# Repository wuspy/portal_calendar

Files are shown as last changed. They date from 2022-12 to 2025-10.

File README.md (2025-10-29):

# Portal Calendar

An ESP32 based, Portal themed e-ink calendar that can run on AAA batteries for years, with optional weather integration through OpenWeatherMap.

- [Bill of Materials](#bill-of-materials)
- [Assembly](#assembly)
- [Firmware](#firmware)
  - [Building with Arduino IDE](#building-with-arduino-ide)
  - [Building with PlatformIO](#building-with-platformio)
- [More Info](#more-info)
  - [Timekeeping](#timekeeping)
  - [Graphics](#graphics)
- [Changelog](#changelog)
- [License](#license)

This project was inspired by Reddit user u/feefifofeddit who made [a prototype of a Raspberry Pi-powered Portal calendar](https://www.reddit.com/r/RASPBERRY_PI_PROJECTS/comments/qujt3i/wip_portal_desktop_calendar/). Unfortunately the display they used has been discontinued, and I wanted a battery powered and wall mountable version, so I designed my own based on the ESP32 platform with the goal of being as low-power and game accurate as possible.

By default, chamber hazard icons from both Portal and Portal 2 are shown below the current date. Portal icons are shown for day 1 through 16, while Portal 2 icons are shown for day 17 through 31.

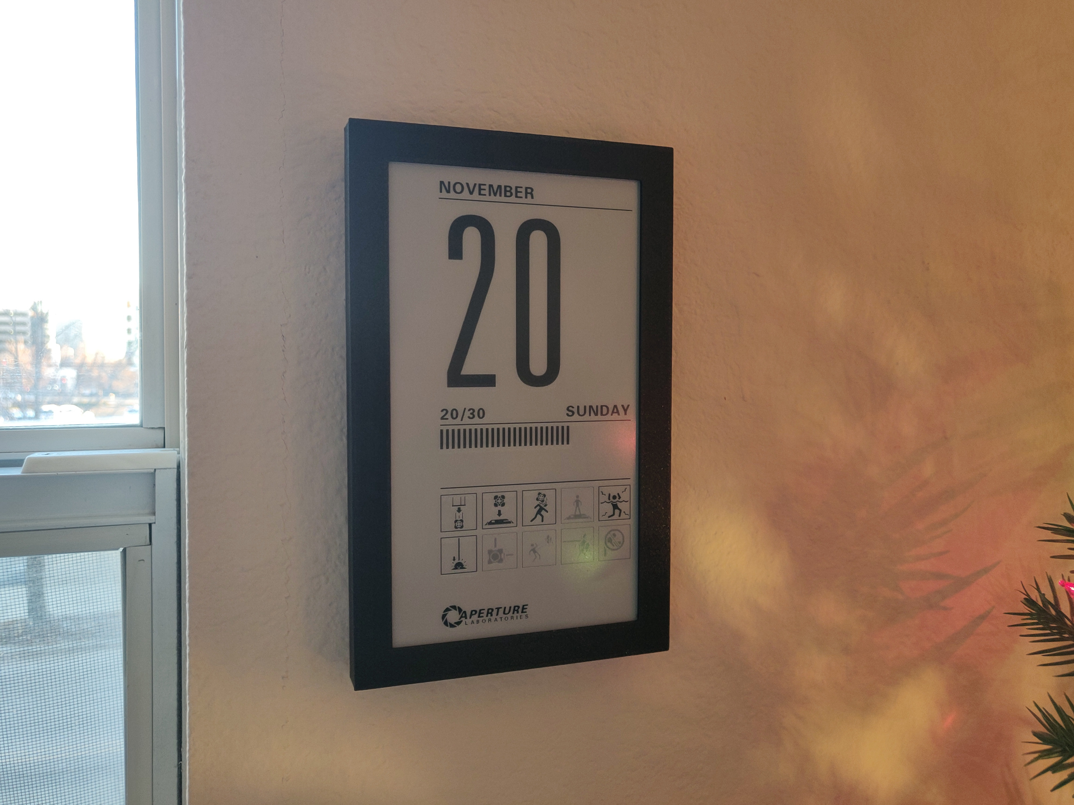
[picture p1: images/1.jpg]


With the weather feature enabled, the chamber hazard icons are replace by either a 5-day or 12-hour weather forecast provided by OpenWeatherMap that shows the average weather condition, the high & low temperatures, the chance of rain, or the humidity, at your preference.

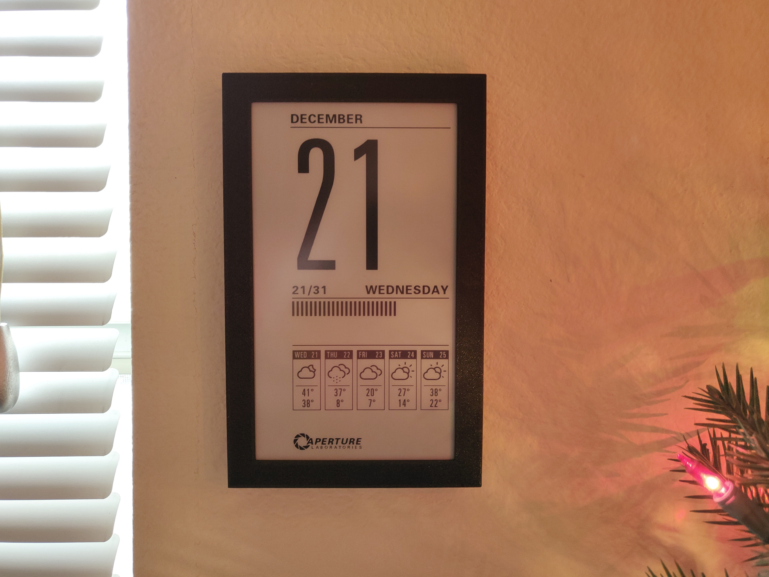
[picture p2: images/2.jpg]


The weather icons are based on the designs by Lukas Bischoff and Erik Flowers, available [here](https://github.com/erikflowers/weather-icons/).

# Bill of Materials

- **Waveshare 7.5" 800x480 E-Ink display**

    Available [directly from Waveshare](https://www.waveshare.com/product/displays/e-paper/epaper-1/7.5inch-e-paper-hat.htm) or [from Amazon](https://www.amazon.com/gp/product/B075R4QY3L). The display itself is the Good Display GDEW075T7, Waveshare just resells it and gives you a breakout board.

    Make sure you buy the bare display with breakout board. Don't buy the one preinstalled in a case. Don't buy the Black/White/Red version of this display either, just the standard Black/White one.

    This display is intended only for 2-color greyscale (full black or full white, with no grey levels). However, this code does some hacks to it to make it support 4-color greyscale for better antialiasing. I didn't invent this technique, the [GxEPD2](https://github.com/ZinggJM/GxEPD2_4G) project among others does the same thing. The downside of doing this, however, is that results can vary from display to display. The greyscale levels may not look as good on your particular display as they do on mine. I've tried to design the graphics with that in mind so that the grey level isn't critical to get things to look good, but I've only tried this on two of these displays, and I can't guarantee yours will look perfect.

- **EzSBC ESP32 breakout board**

    Available [here](https://www.ezsbc.com/product/esp32-breakout-and-development-board/) or [here](https://www.tindie.com/products/ddebeer/esp32-dev-board-wifibluetooth/). This will run on any ESP32, but this particular board is perfect for alkaline battery power due to its efficient voltage regulator and flexible input voltage. If you use a different board, you will need to modify the case and come up with your own power solution.

- **4xAAA battery holder**

    Pretty much all of them will work. [This is a good one](https://www.pololu.com/product/1145/specs).

- **9x M3x8 cap head screws**

# Assembly

Before you begin, note that this project does require soldering and cutting the included display wiring harness. Since it's the most expensive part of the project, I recommend testing your display first before cutting anything so you can easily return it if it's defective. The breakout board comes with pin headers you can solder and directly connect to the stock wiring harness, so I highly recommend skipping down to step 5 and connecting everything up to make sure the dispaly works first. Once you've done that, desolder the pin headers from the breakout board and follow these instructions from the beginning.

1. Print [front.stl](frame/front.stl) and [back.stl](frame/back.stl). Once those are done you can start putting things together, and get [cover.stl](frame/cover.stl) printing while you work. Print with a **0.2mm layer height**, other than that print settings really don't matter that much.
2. Remove the protective film on the front of the e-ink display if it has one (there should be a colored tab in one corner you can pull).
3. Insert the display into [front.stl](frame/front.stl), oriented so the ribbon cable goes into slot on the side. The easiest way to do this is to gently pre-bend the ribbon cable, then slide the display in from the opposite side.

    

    This should go without saying, but the display and the ribbon cable connection are very fragile. Here's a close-up of how the ribbon cable should seat in the slot.

    Recent versions of this display have a slimmer ribbon cable than shown in these pictures, however it should be the same length and have the same pinout, and is fully compatible.

    

    Once it's inserted, make sure the display is sitting flat and that the edges of the display are flush with the edges of the case on the top and bottom.

4. Insert [back.stl](frame/back.stl) on top of the display, flat side down, being careful that the ribbon cable doesn't get snagged when sliding in the slot on the side.

   

   The back cover should be flush with the edges of the front cover. If it's not, the display may not be seated correctly in the front cover. Don't try to force it, remove the back cover and re-seat the display.

   Once the back cover is installed, you can secure it with an **M3x8** screw in each corner.

5. Insert the e-Paper Driver HAT into the slot by the ribbon cable and clip the ribbon cable into the connector. Make sure you get it fully seated in the connector, and **make sure to latch it closed**, otherwise the display may not work when you try to power it on. Also, make sure the **Display Config** switch is in the **B** position, and the **Interface Config** switch is in the **0** position.

6. Now the fun part begins, cutting wires to length and soldering them to the ESP32. Note the colors listed below are the ones used in the wiring harness I got, yours is probably the same but it may be different if Waveshare changed it.

    Note that the PWR pin does not exist prior to revision 2.3 of the waveshare driver board. If you have revision 2.2 or earlier, ignore that pin in the chart below. The firmware will work with both, no other changes are needed.

    | e-Paper HAT   |     | ESP32 |
    | ------------  | --- | ----- |
    | VCC (Grey)    | <-> | 3.3v  |
    | GND (Brown)   | <-> | GND   |
    | DIN (Blue)    | <-> | IO13  |
    | CLK (Yellow)  | <-> | IO14  |
    | CS (Orange)   | <-> | IO15  |
    | DC (Green)    | <-> | IO23  |
    | RST (White)   | <-> | IO33  |
    | BUSY (Purple) | <-> | IO27  |
    | PWR (Red)     | <-> | IO32  |

7. Glue in the battery holder (I used JB weld plastic bonder), and solder the red and black wires to the **Vin** and **GND** pins on the ESP32.

    Here's what everything should look like once wired up. Note that this photo shows the older waveshare driver board without PWR pin.

    

8. Make sure all the wires are inside the recess on the back cover so they aren't pinched, and make sure the ESP32 is seated in its recess. Then you can install [cover.stl](frame/cover.stl) and secure it with an **M3x8** screw in each corner, and one in the center above the battery holder.

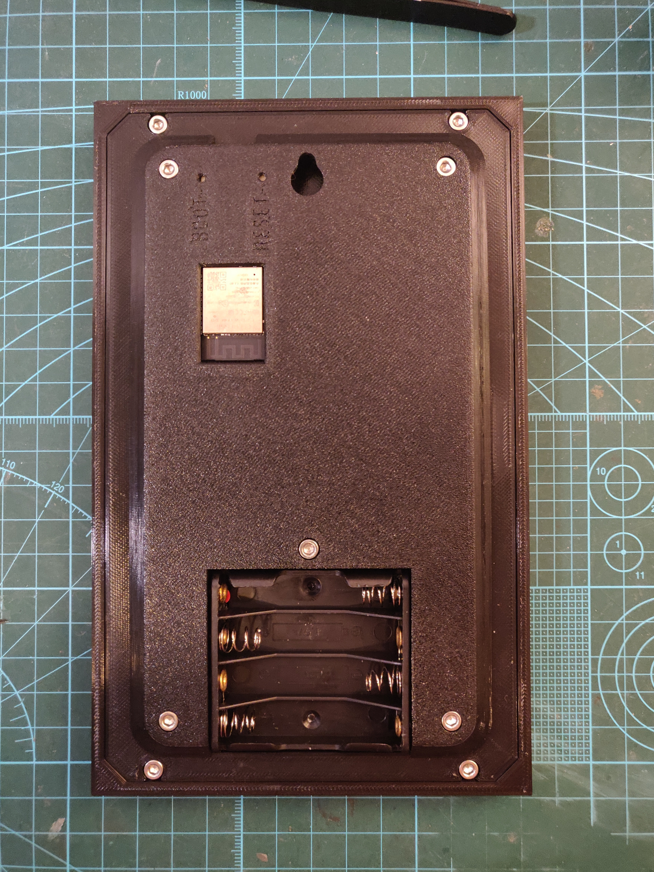
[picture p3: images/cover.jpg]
    

    There's no point in putting the batteries in yet since the ESP32 still needs to be programmed.

# Firmware

## Building with Arduino IDE

This project requires the following dependencies to be installed through the library manager

 - **ArduinoJson** by Benoit Blanchon - 7.4.1
 - **ESP Async WebServer** by ESP32Async - 3.7.7
 - **Async TCP** by ESP32Async - 3.4.1

 Make sure you install the correct versions of these libraries, and for ESP Async WebServer and Async TCP, **install the ones by ESP32Async**, as there are many forks of these libraries out there and I can't guarantee compatability with any others.

 You also need to install the ESP32 board package 3.0+. Go to `Tools -> Board -> Boards Manager...` and search for "esp32". **Install the one by Espressif Systems, not Arduino.**

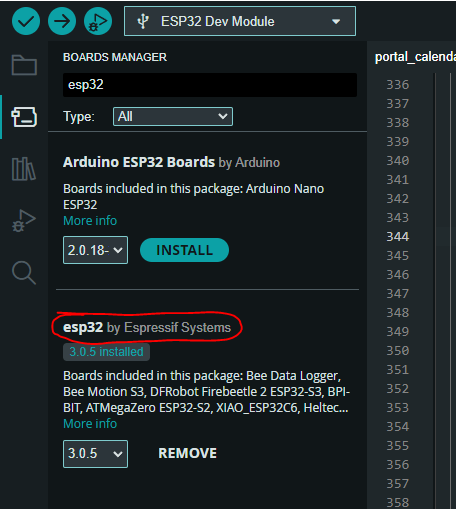
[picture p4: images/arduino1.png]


If you can't find the esp32 board package, you might need an additional board manager URL for it. This shouldn't be necessary anymore, but I'm still including this step just in case. Go to `File -> Preferences` and add the following URL to `Additional Boards Manager URLs`

    https://raw.githubusercontent.com/espressif/arduino-esp32/gh-pages/package_esp32_index.json

After the board package is installed, go to `Select Board -> Select other board and port...` and select `ESP32 Dev Module` for your board.

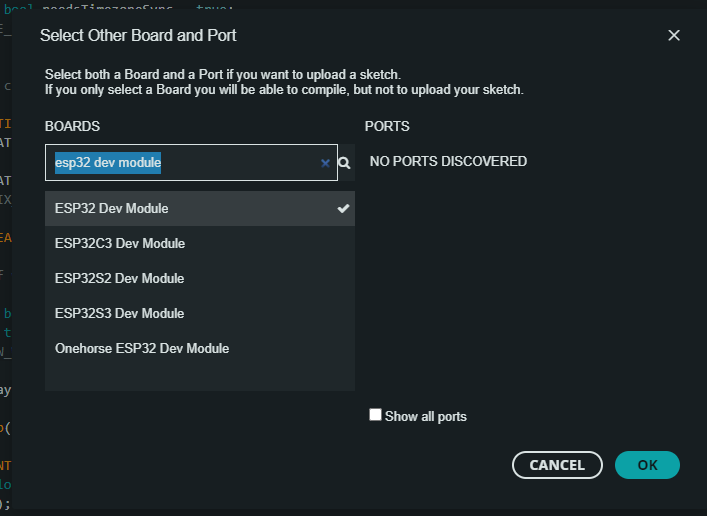
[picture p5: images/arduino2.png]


Once that's selected you'll see a bunch of other options show up in the Tools menu.

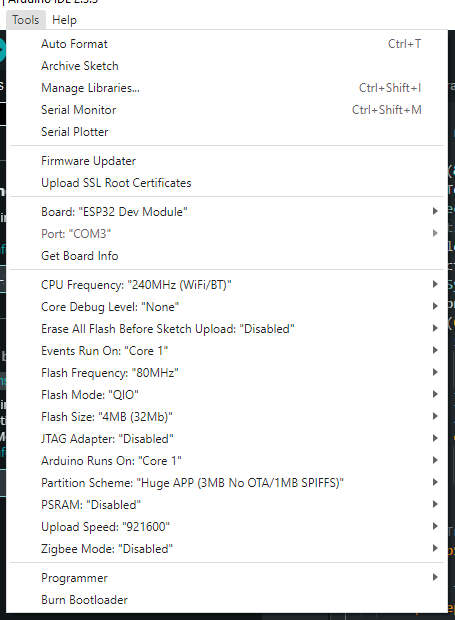
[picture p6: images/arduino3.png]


 **The partition scheme will need to be changed to allow the app to fit.** Other than that, the rest of the options *should* already be what you want, but make sure they match these settings.

 | Option | Value |
 | ------ | ----- |
 | CPU Frequency | 240 Mhz (WiFi/BT) |
 | Core Debug Level | None* |
 | Events Run On | Core 1 |
 | Flash Frequency | 80Mhz |
 | Flash Mode | QIO |
 | Flash Size | 4MB (32Mb) |
 | JTAG Adapter | Disabled |
 | Arduino Runs On | Core 1 |
 | **Partition Scheme** | **Huge APP (3MB No OTA/1MB SPIFFS)** |
 | PSRAM | Disabled |
 | Upload Speed | 921600 |
 | Zigbee Mode | Disabled |

*To enable debug logs, choose `Info` for Core Debug Level. Otherwise, leave it set to `None`.

Now you can just flash it like any other arduino.

## Building with PlatformIO

Assuming you already have PlatformIO installed, there shouldn't be anything else you need to do before building and flashing. Just select Build or Upload under the EzSBC environment.

To enable debug logs, add `-DCORE_DEBUG_LEVEL=3` as a build flag in [platformio.ini](platformio.ini) (it should already be there as a line you can uncomment).

# More Info

## Timekeeping

The internal clock in the ESP32 is very inaccurate with a specified inaccuracy of 5%, which corresponds to 72 minutes per day. This is obviously useless for long-term timekeeping so an external clock is required. One solution would be to use an RTC module like a DS3231, but that still requires an external time source for initialization. Given that, I decided to just ditch that extra cost and require a Wi-Fi connection for daily NTP time syncing, which would be required for OpenWeatherMap anyway if you decide to use it. The default NTP servers are `pool.ntp.org` and `time.google.com`, but they can be changed if you want.

The Wi-Fi connection is also used to lookup information for the timezone you provide, using the timezoned service from the [ezTime project](https://github.com/ropg/ezTime). The default timezoned servers are the original one at `timezoned.rop.nl` and mine at `timezoned.jacobjordan.tech`. This does introduce a failure point if these services both go down, and if that's something you're worried about you can host your own timezoned service. The original PHP code is available in ropg's repository, and my Rust rewirite is availble [here](https://github.com/wuspy/timezoned_rs).

## Graphics

Like I mentioned in the [Bill of Materials](#bill-of-materials) section, I'm doing some hacky stuff with the e-ink display to get it to support 4-color greyscale, both for antaialising and so the inactive chamber icons look better. The specifics on how all this works are outside the scope of this readme, but if you'd like to learn the basics of how e-ink displays work I recommend watching [Applied Science's video](https://youtu.be/MsbiO8EAsGw).

A consequence of this is that I've had to write my own simple 2-bit drawing library for this project, since [Adafruit GFX](https://github.com/adafruit/Adafruit-GFX-Library) doesn't support that and I don't know of any other libraries that do. The low-level code for drawing to the display is located in [DisplayGDEW075T7.cpp](DisplayGDEW075T7.cpp), which includes low-level drawing commands like `setPx`, `drawVLine`, `drawHLine`, `fillRect`, and `strokeRect`, but also more advanced commands like `drawImage`, `drawText`, and `drawMultilineText`, which I'd like to explain a bit further in case you want to modify the icons or fonts used in this project.

All of the bitmap and font resources are in the [resources](resources) directory, which can be compiled to C header files using [build_image.py](resources/build_image.py) and [build_font.py](resources/build_font.py) respectively. I chose to simply compile resources to C code that can be embedded into the firmware instead of loading them from the ESP32's SPIFFS because it greatly simplifies the flashing process.

The build_image.py script can take in any image format supported by PIL and will output a 2-bit-per-pixel [run-length encoded](https://en.wikipedia.org/wiki/Run-length_encoding) C header file of the same name that can be included and drawn to the display. All of the images used in this project are inclued in this repo both as the original GIF images and the compiled C header files.

The build_font.py script will take in TrueType or OpenType fonts and output a bitmap font rendered at the specified size to a C header file, using the same encoding format as build_image. Look at [build_fonts.sh](resources/build_fonts.sh) for usage examples. Unlike for the images, I haven't included the source fonts in this repository because they are the original, proprietary fonts used in the Portal games. If you want to rebuild those fonts, it's up to you to find them online.

# Changelog

### 10/29/2025

* Fix bug in network port assignments.

### 9/14/2025

* Add Portuguese localization.

### 5/25/2025

* Add frame around start screen QR code.

### 5/15/2025

* Switch to ESP32Async's fork of ESP Async WebServer.
* Refactor some display code, and blank the display before/after entering settings mode for quicker feedback.
* Show a crash screen if the device crashed on last boot.

### 10/9/2024

* Add compatibility with arduino-esp32 v3 and latest Arduino IDE.
* Support 64-bit time_t if the environment uses it.

### 2/12/2024

* Add compatibility with Rev2.3 Waveshare driver board.
* Slightly adjust VCOM_DC for a bit better contrast.

### 12/12/2023

* Compress images with simple run-length encoding to save a bit of flash.
* Draw progress bar with vector draw commands instead of an image to save a bit more flash.
* Add STEP file.

### 12/11/2023

* Add the ability to setup the calendar through a web app instead of changing the firmware and re-flashing. There is no longer any need to edit config.h unless you need to change pin assignments or other advanced settings.
* **This update changes the partition scheme.** If you're building with Arduino IDE, read through the Firmware section again and update your build options.

### 4/18/2023

* Add ability to toggle between the weather and chamber icon display using a button on GPIO0.
* Frame REV 04: Fix the boot and reset buttons being labeled backwards, and call the boot button 'mode' since it does something now. If you have frame REV 03 and want to fix this, you only need to print cover.stl since the front and back parts are compatible with it.

# License

* All code in this repository is licensed under the MIT license.
* All images in this repository are licensed under the Creative Commons Attribution-NonCommercial license.
* All STL and 3D CAD files in this repository are licensed under the Creative Commons Attribution-ShareAlike license.

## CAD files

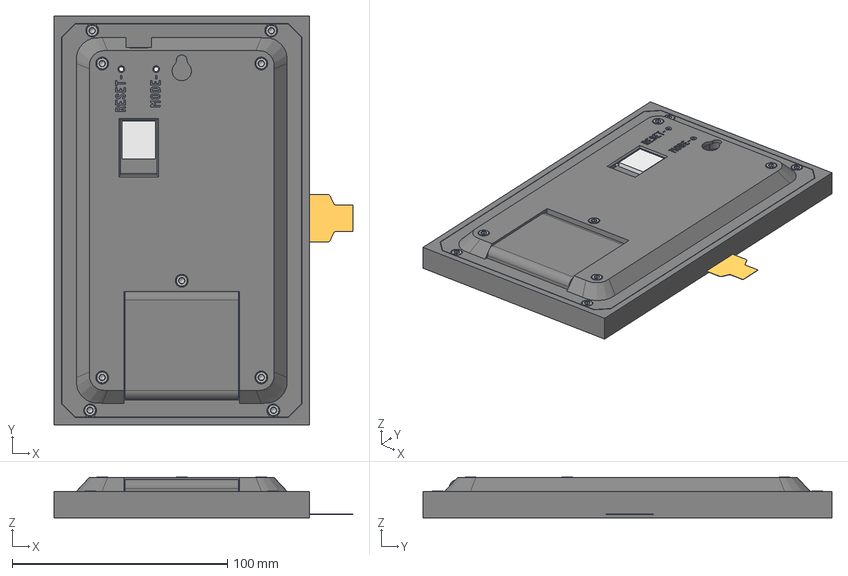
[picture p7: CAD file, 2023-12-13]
frame/frame.step
138.9 x 190.2 x 19.0 mm
Front
Hat
Battery holder
Back
ESP32
M3x8-Screw
M3x8-Screw006
M3x8-Screw007
M3x8-Screw008
Cover
M3x8-Screw017
M3x8-Screw018
M3x8-Screw019
M3x8-Screw020
M3x8-Screw021

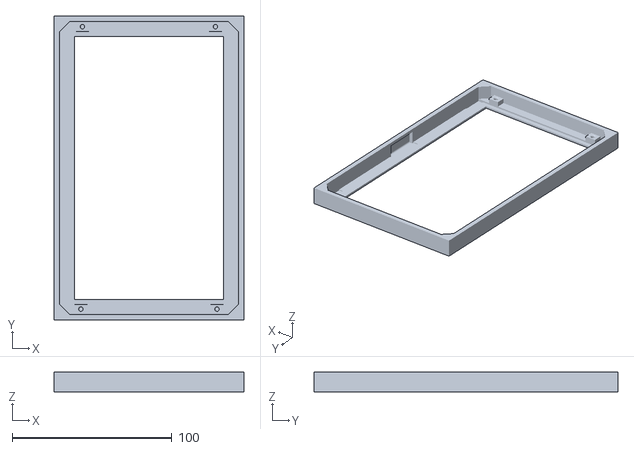
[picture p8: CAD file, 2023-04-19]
frame/front.stl
118.7 x 190.2 x 12.4

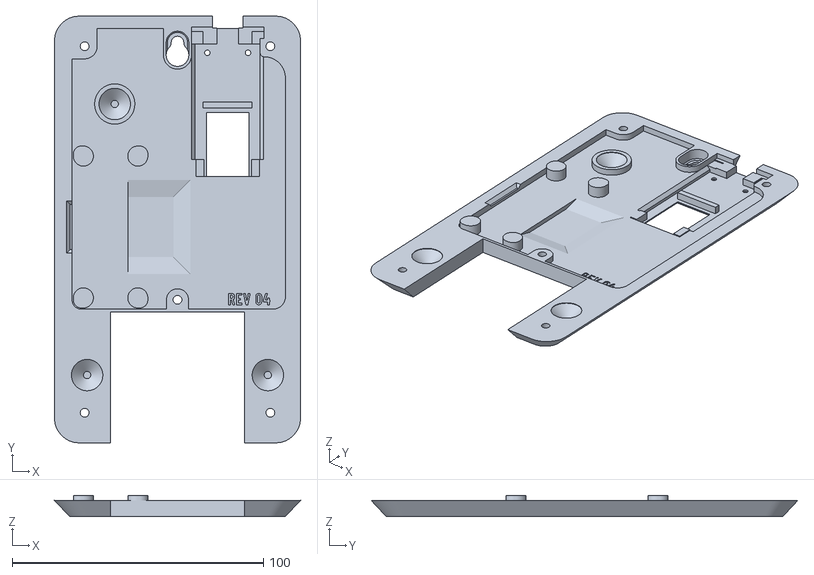
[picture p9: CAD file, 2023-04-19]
frame/cover.stl
98.0 x 170.0 x 8.40

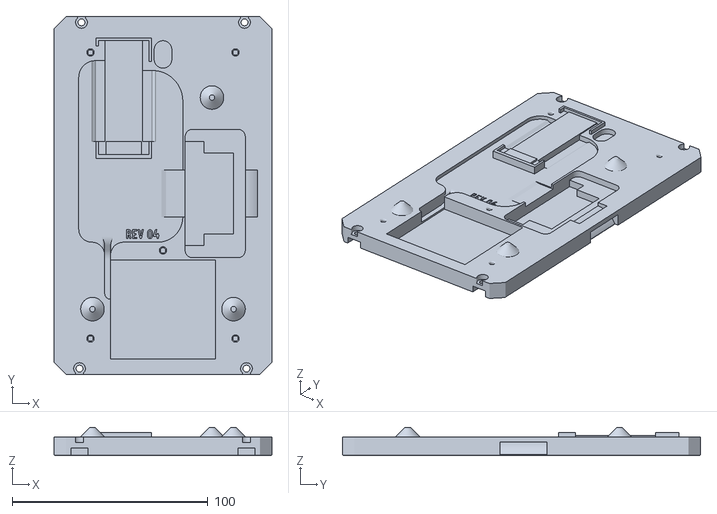
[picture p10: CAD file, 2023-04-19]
frame/back.stl
111.2 x 182.7 x 14.4

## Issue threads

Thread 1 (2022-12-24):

Features I'd like to have

xRealNeon, 2022-12-24:
Hello 👋, I like your project and wanted to build it.

It would be cool if you can implement these features:

1. Display the current Time
2. Get events from caldav/ical and display them

I guess these features would be more power hungry, but if that's the case, I can power it with a power brick.

wuspy, 2022-12-24:
Hey!

Showing the current time would definitely be too power hungry for battery power, since the ESP32 would need to wake up every minute to refresh the display. But beyond that, I'm not really sure if that's even feasible with the e-ink display this uses. Display updates take around 4 seconds and involve the display showing alternating flashes of black and white, so making a clock out of this type of e-ink display would get annoying pretty fast I think. It does have partial update capabilities, but I haven't played around with that so I can't really say if that would work well or not.

Calendar integration is definitely possible and something I thought about adding, but honestly I don't use calendars that much anymore so I probably won't be the one to implement it.

orbatos, 2023-01-02:
Consider fuzzy time or updates only every 10-20 minutes, removing the need for frequent updates as per minute accuracy is not essential.

xRealNeon, 2023-01-02:
The caldav/ical sync would be very cool, the time is not so important

jrdiver, 2023-01-04:
I was thinking making a usb powered version, i think a time option would be interesting, and being able to set it to update that every 5-15 min would be interesting.

Wonder if partial refresh can be done on this display... its available on the smaller panel i have.  would have to check how much power that saves vs full if it is available

xRealNeon, 2023-01-11:
Calendar week would also be a cool information to have

wuspy, 2023-01-12:
Calendar week would be easy enough to do. The top-right is used to show the year if that's enabled, calendar week could go there as an alternative option. I'm open to suggestions though.

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

chrishoage, 2023-01-16:
> Showing the current time would definitely be too power hungry for battery power, since the ESP32 would need to wake up every minute to refresh the display

I plan to build this (waiting on the display) however one thing I thought might be interesting is those "word clocks".

E.g.

"quarter past twelve" / "quarter to eight" / "half past two"

Some of the word clocks online are more granular with 5 or 10 minute intervals, which is overkill for an e-ink display. However a wake up once every 15 minutes might not bee too draining? Particularly if the partial update can be utilized to update a single line (which I think no string would spill over into two lines depending on font size)

Just a thought - excited to build this regardless (though am going to have to rework the 3d models to print the frame in parts on my tiny Prusa Mini+ :sweat_smile:)

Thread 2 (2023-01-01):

Arduino IDE compiling error

JpMaster0, 2023-01-01:
Arduino IDE v. 1.8.13
ESP32  v. 1.0.6 selected ESP32 Dev Module
weird issue

```
C:\Users\USER\OneDrive\Desktop\portal_calendar\portal_calendar.ino: In function 'bool startWifi()':
portal_calendar:94:40: error: no matching function for call to 'WiFiClass::waitForConnectResult(int)'
     if (WiFi.waitForConnectResult(10000) != WL_CONNECTED) {
                                        ^
In file included from C:\Users\USER\AppData\Local\Arduino15\packages\esp32\hardware\esp32\1.0.6\libraries\WiFi\src/WiFi.h:32:0,
                 from C:\Users\USER\OneDrive\Desktop\portal_calendar\portal_calendar.ino:1:
C:\Users\USER\AppData\Local\Arduino15\packages\esp32\hardware\esp32\1.0.6\libraries\WiFi\src/WiFiSTA.h:56:13: note: candidate: uint8_t WiFiSTAClass::waitForConnectResult()
     uint8_t waitForConnectResult();
             ^
C:\Users\USER\AppData\Local\Arduino15\packages\esp32\hardware\esp32\1.0.6\libraries\WiFi\src/WiFiSTA.h:56:13: note:   candidate expects 0 arguments, 1 provided
Found multiple libarys for "WiFi.h"
 Used: C:\Users\USER\AppData\Local\Arduino15\packages\esp32\hardware\esp32\1.0.6\libraries\WiFi
 Not used: C:\Users\USER\OneDrive\Dokumente\arduino-1.8.13\libraries\WiFi
exit status 1
no matching function for call to 'WiFiClass::waitForConnectResult(int)'
```

wuspy, 2023-01-01:
It looks like you have version 1.0.6 of the esp32 boards package installed, this project needs 2.0+. Is there an update available for that package in your boards manager?

JpMaster0, 2023-01-01:
Turns out I had a old board list (url to json file) that was last updated to esp32 version 1.0.6.
By searching for a up-to-date list, replacing the url in the Arduino IDE settings and updating boards i've got the version 2.0.6.
Compiles now fine. Thanks wuspy

Closed 2023-01-01.

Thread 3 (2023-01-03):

EzSBC website instability

Patxi080, 2023-01-03:
Hi, I only want to tell you that the ESP32 link is broken.

wuspy, 2023-01-03:
The EzSBC website? Yeah, I noticed a couple days ago that it was pretty unreliable. I'm still able to access it if I catch it at the right time though.

Even though there's nothing I can really do about this, I'll keep this issue up until they (hopefully) fix it.

Patxi080, 2023-01-03:
Could you tell me what exact ESP32 model you used? I'm asking because it says this in the readme: "This will run on any ESP32, but this particular board is perfect for alkaline battery power due to its efficient voltage regulator and flexible input voltage. If you use a different board, you will need to modify the case and come up with your own power solution." Thx.

wuspy, 2023-01-03:
It's designed & made by EzSBC and and I don't currently know of any resellers.

They do have a store on Tindie though https://www.tindie.com/products/ddebeer/esp32-dev-board-wifibluetooth/

Patxi080, 2023-01-03:
And you used this model because the batteries last longer, right?

wuspy, 2023-01-03:
Pretty much, I couldn't find any other breakout board that came even close to the sleep current that one has. Most of them are designed for LiPo power where sleep current doesn't really matter because you'll be recharging it regularly anyway.

wuspy, 2023-01-04:
Added tindie link to readme in case the site goes down again in the future 01aad1e709e975ea14884324948a4c14a6f3a06f

Closed 2023-01-04.

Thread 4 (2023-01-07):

Dim Display

Kernel-ROM, 2023-01-07:
The display is working but dim.

I can see the screen is able to display black properly when it's starting up/refreshing, but then is faded when loaded.

Do you have any thoughts?

Also, thanks for the awesome project!

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

wuspy, 2023-01-07:
This is pretty weird, I've read that trying to use 4-color grayscale with these displays can have mixed results but I've never seen anything like that. On the e-paper HAT, is the display config switch in the B position?

I just pushed a branch called stock_waveform_test that uses the default 2-color grayscale waveforms that the waveshare examples for this display uses, can you try that out and see if the blacks look better?

Kernel-ROM, 2023-01-08:
Yup, in position B and the exact same hardware as yourself.

The latest changes look drastically better, but the blacks are still not as dark as my other waveshare displays and your own example images. It's useable now though!

I'm starting to think that my display or the HAT are faulty - will contact waveshare.

Thanks for the quick turnaround!

[firefox_zpS99LANEa](https://user-images.githubusercontent.com/1376110/211200296-284a90c9-6de9-42a4-8c88-808927a65fb9.png)

wuspy, 2023-01-08:
I updated stock_waveform_test to revert the remaining settings I changed back to waveshare defaults, if you want you can try that again to see if it looks better. Hopefully it doesn't look better though, because then that would mean your display isn't technically 'faulty' and these displays just have way looser manufacturing tolerances than I thought.

I wish there was more I could do to help, I'm definitely not an expert on e-paper tech. One thing that can be done is adjusting the VCOM_DC level in DisplayGDEW075T7.cpp to tweak the contrast and grayscale levels, but that's more of a fine tuning thing and probably won't help for such an extreme case
```cpp
    sendCommand(CMD_VDCS);  // VCOM DC Setting (min 0x00 = -0.1v, max 0x4F = -4.05v)
    sendData(0x26);         // -2.0v
```

Kernel-ROM, 2023-01-15:
Set it to `0x28` (and using the stock fork) and display looks much closer to the example images.

Many thanks!

Closed 2023-01-15.

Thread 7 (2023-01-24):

Avoiding Hardcoding WiFi Credentials

LordNed, 2023-01-24:
Neat project. I'd like to give one as a gift but teaching friends how to compile and flash an ESP32 might be a bit too much of a gift. I was looking at potentially forking and integrating a wifi manager where, if wifi connection fails, it boots up into access point mode so you can connect to it via your phone and enter wifi credentials, and then have them saved on the device.

Looking around it looks like there's a package for the ESP32 by user Tzapu - https://github.com/tzapu/WiFiManager. Is this something you're interested in taking a pull request to add? If so, do you have thoughts on how you would want it implemented. I can make an effort to implement it that way to make it easier to take back as a PR.

My initial thoughts were to just set up a new set of defines in the header, instead of:

`#define WIFI_NAME "your wifi name here"
#define WIFI_PASS "your wifi password here"`

Have something like
```
#define USE_ACCESS_POINT_CONFIG 1
#if USE_ACCESS_POINT_CONFIG
// IP Address the device will create a webserver on to config
#define WIFI_ACCESSPOINT_NAME "Aperture Labs Non-Sentient Devices"
#define WIFI_ACCESSPOINT_PASSCODE ""
#else
#define WIFI_NAME "your wifi name here"
#define WIFI_PASS "your wifi pass here"
```

And then whatever changes need to be made to the cpp files to branch them based on #if USE_ACCESS_POINT_CONFIG or not. I won't be able to tinker around with the code for a while until an ESP32 gets here but skimming both portal_calender.ino and the examples for the WiFiManager it looks relatively straightforward. The WiFi Manager will block the init loop until successfully connected to a real wifi connection, though it would be handy if we could display a string with instructions (connect to access point, navigate to any webpage on device, get redirected to config page, enter credentials, etc.)

wuspy, 2023-01-27:
I think this would be a great feature and it's something I wanted to do originally. Ideally, all settings would be configurable from the web UI, then config.h wouldn't even be necessary and there would never be a need for an end user to re-flash.

However, it's not ideal to have it running an AP on battery power, and it's definitely not a good idea to have it automatically fall-back to the AP in case the wifi connection fails since it could potentially be running it on battery power for hours before the user notices. Luckily this board does have a way to detect if its running on USB power, so we could make a workflow where it instructs them to plug the device in to begin setup, then goes to sleep, waking up every second or two to check if it's on USB power yet, then starts the AP and displays the SSID and password on the display, maybe even with a [QR code](https://github.com/nayuki/QR-Code-generator/tree/master/cpp) if we want to be fancy.

```cpp
/**
//  * On the EzSBC breakout board, pin 19 is connected to Vusb through an LED and a 1k resistor, meaning it is pulled
//  * high if the board is on USB power.
//  */
bool isOnUsbPower()
{
    pinMode(19, INPUT_PULLDOWN);
    return digitalRead(19) == HIGH;
}
```

I haven't taken current measurements of it in AP mode so I could be overestimating how much of a problem this is, and spending 10 minutes in AP mode while the user completes the setup might not be a big deal. However it's also possible that they could put in the batteries, and then just not touch it for a couple days without realizing that its rapidly draining them down.

So yeah, I'm definitely open to a pull request if you want to take a shot at this.

LordNed, 2023-02-04:
Still no ESP32 but started poking around the code tonight. I didn't want to make a fork with a bunch of untested checkins, but wanted to run proposed code/flow changes by you;

1) startWifi/stopWifi route through the wifiManager now. the WiFiManager is told to not automatically make an AP when attempting an autoconnect, so it should attempt to connect for 10s, then fail and shut down wifi.

```
void stopWifi()
{
    if (WiFi.getMode() != WIFI_OFF) {
        DEBUG_PRINT("Stopping WiFi");
        unsigned long start = millis();
        wifiManager.disconnect()

        // Disable the WiFi hardware as well for power preservation.
        WiFi.mode(WIFI_OFF);
        DEBUG_PRINT("WiFi shutdown took %lums", millis() - start);
    }
}

bool startWifi()
{
  // Ensure the device is in Station Mode
  WiFi.mode(WIFI_STA);

  // If we're already connected, don't bother trying to connect again
  if(wifiManager.getLastConxResult() == WL_CONNECTED) {
    return true;
  }

  DEBUG_PRINT("Starting WiFi");
  unsigned long start = millis();

  // If we're not already connected, attempt to connect. By default WiFiManager will automatically
  // try to start an Access Point if connection fails (so you can connect to WiFiManager and configure)
  // but we suppress that behavior, so that we can display some info to the user.
  wifiManager.setEnableConfigPortal(false);
  wifiManager.setWiFiAutoReconnect(false);
  wifiManager.setConnectTimeout(10); // Attempt to connect for ten seconds, then fail.

  // If there's no credentails to try and connect with, don't bother with the connection attempt.
  bool result = wifiManager.getWifiIsSaved();
  if(!result) {
    DEBUG_PRINT("No WiFi Credentials Saved, moving user to AP Setup Flow");

    // We call stopWiFi to clean up and shut down WiFi as much as possible
    stopWiFi();
    return false;
  }

  // If they do have credentials saved, attempt a connection.
  result = wifiManager.autoconnect();
  if(!result) {
    DEBUG_PRINT("WiFi connection failed after %lums, moving user to AP Setup Flow", millis() - start);

    stopWiFi();
    return false;
  }

  // If we got this far then they managed to connect to WiFi!
  DEBUG_PRINT("WiFi connection succeeded, took %lums", millis() - start);
  return true;
}
```

In setup() we now need to attempt to start the wifi before anything else like TIME_ZONE syncing, with a new error message prompting the user to plug into USB power. It wasn't clear to me from your code snippet if that was a function in an ESP32 library or not.
```
... existing debug logging code...
    // If we're rebooting because we ran out of power, print an error
    // (and this function never returns, the rest of setup is not run)
    if (esp_reset_reason() == ESP_RST_BROWNOUT) {
        errorBrownout();
    }

    // Attempt to connect to the WiFi. If connection fails then either credentials are wrong,
    // it's never been set up, or it's out of range.
    bool bConnectedWiFi = startWiFi();

    if(!bConnectedWiFi)
    {
        // We failed to connect to the WiFi. We're going to ask the user to plug into USB power
        // instead of running the AP without them realizing it.
        if(!isOnUsbPower())
        {
            // If they're not currently on USB power, we will print an error message
            // asking them to plug in via USB, then restart. This function will never
            // return (enters deep sleep).
            errorNotOnUSBPowerToStartAP();
        }

        // If we are on usb power, we're going to start an Access Point that the user
        // can connect to with their phone to configure this display. This will print
        // some info to the screen
        doDeviceConfigurationFlow();
    }
```

doDeviceConfigurationFlow will start the Access Point. It took a while of digging around but it looks like the way WiFi QR codes work is just a pre-made pattern of text as the data for the QR Code (untested):
`WIFI:S:<SSID>;T:<WEP|WPA|blank>;P:<PASSWORD>;H:<true|false|blank>;;`
(H being hidden SSID I think). And the trailing two ";;" are important apparently.

I suspect in practice we'll want an actual QR Code drawing routine instead of encoding it into text - I have no idea what this will look like on an actual device. Also too bad the QR Code library doesn't support image overlays, could put a little Aperture Logo in the center of the QR code :)

```
void doDeviceConfigurationFlow()
{
    // To configure the device, the ESP32 will create an Access Point with a username/password.
    // The user will then connect to it via their phone, setup the access to the real WiFi
    // and then the ESP32 will close the Access Point and attempt to connect to the user-specified one.

    // We want to inform the user how to configure their Aperture Science Non-Sentient Device,
    // so we will take advantage of the screen to display some info + a QR Code to scan with the phone.
    // We can't use the standard error(...) function as that will enter deep sleep and prevent us from
    // ever starting the webportal.
    DEBUG_PRINT("Starting Device Configuration Flow");
    unsigned long start = millis();

    // ToDo: Find out if the ESP is WPA2 or WEP when in AP mode
    // To generate a QR Code that helps auto-connect your phone to a WiFi network, the
    // QR Code needs to have the following pattern, where H: means "Hidden" and is optional.
    // The trailing ";;" is important. Side note: This could probably be rewritten to cause
    // less heap fragmentation, since this info is the hard-coded Device AP, not user AP.
    // WIFI:S:<SSID>;T:<WEP|WPA|blank>;P:<PASSWORD>;H:<true|false|blank>;;
    String QRCodeData = String("WIFI:S:") + WIFI_AP_NAME + String(";T:WPA;P:") + WIFI_AP_PASSWORD + String(";H:false;;");

    // Now that we have the data as a string, we will generate a qr code.
    qrcodegen::QrCode qrCode = qrcodegen::QrCode::EncodeText(*QRCodeData, QrCode::Ecc::MEDIUM);

    // Finally, we refresh the display to show this information to the user. We could probably write a native QR Code drawing
    // routine for the display... or we could encode the QR Code as text and re-use the existing routine for displaying text. :)
    // (this is definitely not great for heap fragmentation, but also there's like 160kb of it...)
    String qrCodeAsString;
    int border = 4;
    for(int y = -border; y < qrCode.getSize() + border; y++)
    {
        for(int x  = - border; x < qrCode.getSize() + border; x++)
        {
          qrCodeAsString += qrCode.getModule(x, y) ? "##" : "  ";
        }
        qrCodeAsString += "\n";
    }

    std::initializer_list<String> userText =
    {
      "Welcome to your Aperture Science Non-Sentient Device",
      "Please configure your device by using another WiFi",
      "capable Device (such as your phone) and connecting",
      "to the WiFi Network:",
      "SSID: \""WIFI_AP_NAME"\"",
      "Password: \""WIFI_AP_PASSWORD"\"",

      "Alternatively, you can scan the QR Code below to",
      "automatically be connected to \""WIFI_AP_NAME"\".",
      "",
      "",
      qrCodeAsString
    };

    // Draw our QR Code + User Prompt to Display, reusing the routine for displaying an error.
    const bool bWillRetry = false;
    display.error(userText, bWillRetry);

    // The startConfigPortal will block until the user confirms information.
    wifiManager.setConfigPortalBlocking(true);
    wifiManager.startConfigPortal(WIFI_AP_NAME, WIFI_AP_PASSWORD);
}
```

The hard-coded #if WEATHER won't work with dynamic webpage-based configuration. Do you want to gate these behind a `RTC_DATA_ATTR bool` property and do them dynamically? It isn't clear if there are any downsides to always including all the #ifdef'd functionality (weather, timezone, etc) (such as needing a third party library or not enough ROM space to have them all enabled, etc.)

I don't know if the WiFiManager webpage gives us enough controls or not, but would be neat if you could program someone's birthday in and have it do a full-screen Portal Birthday Cake drawing on the day, but probably beyond what I'm willing to do. :)

Closed 2023-12-11.

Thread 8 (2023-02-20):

Hostname, SPI pins, and other improvments

chrishoage, 2023-02-20:
I hacked on your project this weekend.

I made the following improvements:

1. Allow a hostname (I wanted something more recognizable in my network, I have a ton of ESP devices :sweat_smile:)
2. Allow specifying SPI pins (when using HSPI on my ESP32S2 none of the pins are defined - and need to be manually defined)
3. Toggle between chamber and weather display using the GPIO 0 button (e.g. boot button)

https://user-images.githubusercontent.com/1056886/220210141-7406e1ac-9b14-4275-9178-c0dba52aa30b.mp4

See the changes here in a comparison:

https://github.com/wuspy/portal_calendar/compare/master...chrishoage:portal_calendar:hoage/improvements

If you would like any of these to be upstream let me know! I'd be happy to cherry pick the commits to branches and open PRs.

Thank you for your wonderful project :slightly_smiling_face: (sorry for opening an issue - github discussions don't seem to be enabled!)

wuspy, 2023-02-25:
I left a couple comments on the commits. Configurable hostname and SPI pins sounds great, if you wanna open a PR for those I'll merge them. I also think switching between icons & weather is a really good idea, but open a separate PR for that since it's a bigger change that I want to look at and test a bit more.

chrishoage, 2023-02-27:
@wuspy Sounds good! I opened the SPI and Hostname PRs. I want to rework the toggle one. Right now I'm relying on EEPROM but I discovered `RTC_DATA_ATTR` which is what I originally wanted.

An aside: Depending on the outcome of https://github.com/wuspy/portal_calendar/pull/11 it might be worth renaming `config.h` to `example_config.h` and adding `config.h` to `.gitignore.` (possibly also a `defaults.h` with some `ifndef` to set defaults for weather and other options)

It's a dance to keep my local SPI / wifi / other config changes from getting commited - in particular when working on config.h itself.

Closed 2023-04-19.

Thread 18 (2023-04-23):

Bad Contrast with waveshare board

jhughesbiot, 2023-04-23:
I initially set this up with an esp32 I had on hand but it only worked once then would not update the display anymore.  I bought this board https://www.waveshare.com/wiki/E-Paper_ESP32_Driver_Board#Pin to remove doubt about the board and after tweaking the code a bit to make the spi pins compatible, it does update but the image is super faint.  I can run the waveshare demos and do not see this faint image and text so I know the display is fine as well as the connection.  Only difference is using this library vs theirs.  Any thoughts on what could be the difference in causing the bad contrast on the screen?

wuspy, 2023-04-24:
Does the display look similar to #4? The display code this uses is different from the waveshare examples because it supports 4-color grayscale, with the downside that it may not work well on every display. Unfortunately there's not much I can do to help since I'm no expert on e-paper tech, and both of the displays I have work fine so I can't test out different settings. There are a few things you can try though.

1. Adjust the VCOM_DC value in DisplayGDEW075T7.cpp. That will definitely change the contrast, I've thought about moving it to config.h under a contrast setting but I don't know if adjusting it too far one way or the other could damage the display over time.
    ```cpp
    sendCommand(CMD_VDCS);  // VCOM DC Setting (min 0x00 = -0.1v, max 0x4F = -4.05v)
    sendData(0x26);         // -2.0v
    ```
2. Try out the stock_waveform_test branch, that uses the same settings as the waveshare example but grayscale won't work. It looks like the only non-grayscale related settings I changed were the values for VCOM_DC and CDI. This project could definitely be made to work with the stock settings, the graphics would just need to be changed to replace grayscale with dithering.
3. If all else fails return your display and buy another one, if you're able to. I don't know the percentage of display that have issues with these settings but you're only the 2nd person to open an issue about this so hopefully it's not that high.

jhughesbiot, 2023-04-25:
Yes, that is the exact scenario I was having.  I attempted to adjust the VCOM setting all the way up to 0x35 incrementally and saw very little improvement.  I stopped at 0x35 due to the note concerning possible damage to the screen based on this setting so wanted to stay away from the extremes.  Some improvements in beginning of the display but not much if anything towards the middle and bottom.

 I switched to the stock_waveform and that does look a lot better but since this has no grayscale, any icon at the bottom that was supposed to be faded out, was just gone.  Not the end of the world if I add the weather since I think there's nothing left to need the grayscale but not 100% on that one.

I have also opened a ticket with waveshare and shared the dim image so we'll see what they say.

jhughesbiot, 2023-04-25:
Just gave that branch a shot but looks very much the same as the main branch.  Tried to modify the VCOM_DC value just to see what would happen but no luck there either.

jhughesbiot, 2023-04-26:
For what it's worth, I implemented a weather api key and am running on the stock_waveform branch so it looks good.  I can switch back to the icons with the boot button easily if there's anything to test further.

jhughesbiot, 2023-05-06:
I received replacement hardware from waveshare and confirmed that I had a bad hat which was making connections to the wire harness impossible.  After confirming this, I ran through a series of tests to check other scenario's where I had seen issues with the image.  I will leave the results here for anybody else finding similar issues:

<html xmlns:v="urn:schemas-microsoft-com:vml"
xmlns:o="urn:schemas-microsoft-com:office:office"
xmlns:x="urn:schemas-microsoft-com:office:excel"
xmlns="http://www.w3.org/TR/REC-html40">

<head>

<meta name=ProgId content=Excel.Sheet>
<meta name=Generator content="Microsoft Excel 15">
<link id=Main-File rel=Main-File
href="file:///C:/Users/JONATH~1/AppData/Local/Temp/msohtmlclip1/01/clip.htm">
<link rel=File-List
href="file:///C:/Users/JONATH~1/AppData/Local/Temp/msohtmlclip1/01/clip_filelist.xml">
<style>
<!--table
	{mso-displayed-decimal-separator:"\.";
	mso-displayed-thousand-separator:"\,";}
@page
	{margin:.75in .7in .75in .7in;
	mso-header-margin:.3in;
	mso-footer-margin:.3in;}
tr
	{mso-height-source:auto;}
col
	{mso-width-source:auto;}
br
	{mso-data-placement:same-cell;}
td
	{padding-top:1px;
	padding-right:1px;
	padding-left:1px;
	mso-ignore:padding;
	color:black;
	font-size:11.0pt;
	font-weight:400;
	font-style:normal;
	text-decoration:none;
	font-family:Calibri, sans-serif;
	mso-font-charset:0;
	mso-number-format:General;
	text-align:general;
	vertical-align:bottom;
	border:none;
	mso-background-source:auto;
	mso-pattern:auto;
	mso-protection:locked visible;
	white-space:nowrap;
	mso-rotate:0;}
-->
</style>
</head>

<body link="#0563C1" vlink="#954F72">

e-ink esp32 dev   board | Main Branch | stock_waveform_test | alternate_display_settings_test
-- | -- | -- | --
Built in ribbon connection | faint overall image, greyscale icons basically invisible | Good dark images, no greyscale, faded icons missing entirely | Good dark images, no greyscale, faded icons missing entirely
Wire harness to driver hat | All Good | Good dark images, no greyscale, faded icons missing entirely | Good dark images, no greyscale, faded icons missing entirely

</body>

</html>

<html xmlns:v="urn:schemas-microsoft-com:vml"
xmlns:o="urn:schemas-microsoft-com:office:office"
xmlns:x="urn:schemas-microsoft-com:office:excel"
xmlns="http://www.w3.org/TR/REC-html40">

<head>

<meta name=ProgId content=Excel.Sheet>
<meta name=Generator content="Microsoft Excel 15">
<link id=Main-File rel=Main-File
href="file:///C:/Users/JONATH~1/AppData/Local/Temp/msohtmlclip1/01/clip.htm">
<link rel=File-List
href="file:///C:/Users/JONATH~1/AppData/Local/Temp/msohtmlclip1/01/clip_filelist.xml">
<style>
<!--table
	{mso-displayed-decimal-separator:"\.";
	mso-displayed-thousand-separator:"\,";}
@page
	{margin:.75in .7in .75in .7in;
	mso-header-margin:.3in;
	mso-footer-margin:.3in;}
tr
	{mso-height-source:auto;}
col
	{mso-width-source:auto;}
br
	{mso-data-placement:same-cell;}
td
	{padding-top:1px;
	padding-right:1px;
	padding-left:1px;
	mso-ignore:padding;
	color:black;
	font-size:11.0pt;
	font-weight:400;
	font-style:normal;
	text-decoration:none;
	font-family:Calibri, sans-serif;
	mso-font-charset:0;
	mso-number-format:General;
	text-align:general;
	vertical-align:bottom;
	border:none;
	mso-background-source:auto;
	mso-pattern:auto;
	mso-protection:locked visible;
	white-space:nowrap;
	mso-rotate:0;}
-->
</style>
</head>

<body link="#0563C1" vlink="#954F72">

Node MCU 32s | Main Branch | stock_waveform_test | alternate_display_settings_test
-- | -- | -- | --
Wire harness to driver hat | All good | Good dark images, no greyscale, faded icons missing entirely | Good dark images, no greyscale, faded icons missing entirely

</body>

</html>

In summary, from my testing, I wouldn't use the e-ink esp32 with the built in ribbon connection unless you only want to use the weather option and prefer simpler wiring but don't use the main branch if you do or the image will not be good.  Main branch is the only one that actually worked with grey scale for me so any generic esp32 should work and if there are issues with the image, it's probably due to a faulty hat rather than the screen.

Closed 2023-05-06.

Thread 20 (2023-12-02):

Blank Screen

Zachoeser, 2023-12-02:
Hello! I am excited to say im on the last step of this project. Your instructions have been wonderful.  I have assembled my board in the 3d printed frame and am to the programming stage. I have successfully uploaded the config fille in IDE under both the void setup and void loop areas of the programming. However the screen never lights up or displays any information. This is my time with Arduino and i feel like i may be missing a step. I have done plenty of googleing but would  appreciate some help. Thank you!
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

Closed 2023-12-04.

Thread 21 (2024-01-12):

USB Power Not Detected

jhughesbiot, 2024-01-12:
I had a previous version of this project running on an esp32 board that was not the same one used in the description without issue.  I saw that there was a lot of updates recently and wanted to try it so after compiling and uploading without any changes, I get a Not on USB power message, which it is.  I don't see any additional wiring that's going on or anything other than setting some pin behaviors for PIN 19.  Is this a specific behavior to this board?

I do actually have the same board in the hardware specs and tested with that one and it does detect USB power.  Same code, two different esp32 dev boards, different usb power behaviors so not sure if this is a specific feature to this board or the choice of pin 19 is specific to the board.

wuspy, 2024-01-12:
Yeah, unfortunately #17 added some code specific to this board to determine if it's running on USB power. Vusb is connected to pin 19 through an LED and a 1k resistor. You can check to see if the board you're using has some method for determining if it's running on USB power and then change the value of PD_PIN in config.h to match it, or write some custom code if it's not as simple as just checking a pin. Most boards don't have such a feature though.

If you're dead set on using this board you can always add a switch on some unused pin and use that to trigger the web server. Or even bodge a resistor divider or a similar LED/resistor pair between Vusb and a random pin. I don't actually know if the ESP32 is 5v tolerant so just running a wire might not be safe. Or of course you could just keep running the last commit before that PR was merged, no other new features have been added yet.

Closing for now since this is related to an unsupported board.

Closed 2024-01-12.

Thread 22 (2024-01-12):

Waveshare E-Paper Driver Board Rev2.3

YeahBob, 2024-01-12:
Note: Waveshare has updated their e-paper driver board to Rev2.3.  This project is designed to work with Rev2.2. If you have the Rev2.3 board, you will need to solder a 47k resistor to the pads on the back of the board shown here:
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
Do not connect the PWR pin. This will ensure this board works with this project without the need to modify any files or pin assignments. More details can be found here:
https://www.waveshare.com/wiki/E-Paper_Driver_HAT
Hopefully this helps anyone who tries this project in the future! :D

wuspy, 2024-01-12:
I didn't know they released a new revision, thanks for bringing this up. I'll try to get the code updated to handle it once I have one to test. I'd rather not make surface mount soldering required for this project.

falkzeh, 2024-01-26:
I just encountered this and connected the `PWR`  pin to 3.3v. So my mapping is:

| e-Paper HAT   |     | ESP32 |
| ------------  | --- | ----- |
| VCC (Grey)    | <-> | 3.3v  |
| PWR (Red)     | <-> | 3.3v  |
| GND (Brown)   | <-> | GND   |
| DIN (Blue)    | <-> | D13   |
| CLK (Yellow)  | <-> | D14   |
| CS (Orange)   | <-> | D15   |
| DC (Green)    | <-> | D23   |
| RST (White)   | <-> | D33   |
| BUSY (Purple) | <-> | D27   |

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

Seems to work so far. @wuspy Let me know if I can be of any assistance when it comes to updating docs/ code.

wuspy, 2024-02-12:
@falkzeh I got one of the new driver boards and did some testing with it, and although wiring PWR straight to 3.3v works it uses far too much idle power in my testing. The new revision measured at Vin draws 430uA in deep sleep, while the old one draws just 12uA. That kind of parasitic power draw would kill AAA batteries in a few weeks. So it looks like I'll need to look into the changes waveshare made to their example code to see what they're doing, hopefully it's just a simple as switching PWR before a display refresh. Disconnecting PWR on the new driver board does drop it down to 12uA just like the old one.

My test setup involves just bridging a cheap multimeter across one of the battery contacts so it isn't the most accurate thing in the world, but I've tried it several times while swapping the driver board back and forth and so I'm fairly confident in these results.

wuspy, 2024-02-12:
[This is the commit in waveshare's examples adding support for this board.](https://github.com/waveshareteam/e-Paper/commit/a550cc47fa320d2ae7d89d6028452ce01c11ef1d) Like I suspected they're just wiring it to a pin that's set high when the display is initialized, although they're never setting it low again which is strange. I'm doing something similar, writing it to IO26 and setting it high in wakeup() and low and sleep() and it seems to work fine, power usage in sleep is the same as it was before. I'll do a bit more testing then update the code and documentation.

wuspy, 2024-02-13:
Fixed in 11559a0

Closed 2024-02-13.

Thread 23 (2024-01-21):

Vertical Bars under Date and Day

Zachoeser, 2024-01-21:
I have read through the guide many times and I am not sure if i missed it or the information is not available. What do the vertical bars in the center of the screen under the date and day of the week represent? thank you

wuspy, 2024-01-21:
It's a progress bar. In Portal it shows how far you are through the current set of test chambers, here it shows how far you are through the current month.

Closed 2024-01-21.

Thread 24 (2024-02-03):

Stuck in Setup-Mode?

legrex, 2024-02-03:
Hi,

thanks for your project, had a lot of fun printing, soldering and putting it all together. Just finished an hour ago and had it up and running with the Weather showing for the next 5 days. Then i wanted to see how the Forecast-Mode for just the current day looks and pressed reset and went back to the web-installer and configured it. So then i get the

"Setup Complete

You can now close this page and unplug the calendar. If you want to change something later, plug in the calendar and press the RESET button on the back to enter setup mode again."-Message

But after that i'm lost. The Display still shows the QR-Code and Setup-Instructions. If i Power-Cycle it always goes back to this, issueing a new wifi-key. So i have no idea how to get to the Calendar-View again? Am i missing something, did i miss to read about a step?

Thank you again,
sincerely,
Grex

wuspy, 2024-02-03:
If it's going back to the welcome screen then that means one of these checks is failing
```cpp
bool ConfigurationClass::isConfigured()
{
    return !(
        getWifiSsid().isEmpty() ||
        getTimezoneName().isEmpty() ||
        getPrimaryNtpServer().isEmpty() ||
        getPrimaryTimezonedServer().isEmpty() ||
        (getWeatherEnabled() && (
            getOwmApiKey().isEmpty() ||
            getWeatherLocationLatitude() == 0.0 ||
            getWeatherLocationLongitude() == 0.0
        ))
    );
}
```
The setup app shouldn't let you continue if that's the case so there's probably a bug in the validation it's doing. Is your API key and location filled out on the weather page, and do they both turn green? If you disable the weather, does it work?

legrex, 2024-02-03:
That was the first i tried, disabling weather but with the same outcome. Also all Fields in this check are filled out and API-Key and Location turning green. Maybe i "destroyed" a solder joint at the end and the display is just not updating? Are IO13-15 for the Control of the e-ink-display?

wuspy, 2024-02-03:
Oh I think I misread your message, I thought it was going back to the welcome screen telling you to connect to power, but it's actually just staying on the QR code screen. If that's the case then it must think it's still connected to power, which could only happen if IO19 is pulled high. Do you have some soldering bridging that to Vin maybe?

And yes IO13-15 are used for controlling the display, so those need to be well connected and not shorted together. Is the display going through a refresh cycle (alternating black/white) when you press reset or does nothing happen at all?

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

legrex, 2024-02-03:
You're totally right. Vin was correctly soldered, but i did not cut the something to long wire down and as i was assembling the Cover it must have shortened IO19. I cut it now and it's working. Thank you so much!

Closed 2024-02-03.

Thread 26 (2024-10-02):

Compil error

TumangShenyon, 2024-10-02:
I got this project to run once (after getting the changes for Rev2.3), and tried to update my Arduino IDE after that.
Now I get some compil error with the [[noreturn]] tag:
```
error: function 'void deepSleep(time_t)' declared '[[noreturn]]' but its first declaration was not
   36 | [[noreturn]] void deepSleep(time_t seconds)
      |                   ^~~~~~~~~
```

I managed to fix it by adding a forward declaration with the noreturn, and removing it from the function, hoping the tag will stay active.
I also needed to update ESPAsyncWebSrv  to 1.2.8

But then I got another problem with the SPI:
`[   526][E][SPI.cpp:116] begin(): Attaching pins to SPI failed.`

Was there a change in the SPI library recently? I don't really know how to fix this, my wiring is still the same.

wuspy, 2024-10-03:
I'm able to reproduce both of these issues. The [[noreturn]] issue can be easily worked around by just removing that tag from all the functions using it in portal_calendar.ino, it's really only for documentation and minor compiler optimization and doesn't actually affect the behavior of the code. I have no idea why the latest version of Arduino IDE has an issue with it.

For the SPI issue... I'm not sure yet. I'll look into it a bit more this week. There's been a new major version of the ESP32 board package released since I last tested this, so that's a likely culprit. Also, I can't reproduce either of these issues in PlatformIO, so if you want to get up and running now you can setup a VSCode + PlatformIO environment and built it with that.

Either way, I do need to actually spend some time testing this with the new major versions of the ESP32 board package and ArduinoJson, and most of my screenshots in the readme are out of date with the latest version of Arduino IDE. So I'll update those in the same MR I (hopefully) fix the SPI issue in.

wuspy, 2024-10-07:
I've opened #27 to address this, if you have time can you check it out and verify if it works for you? It'll probably be a few days before it's merged anyway since I need to do my own testing on it and update the screenshots.

wuspy, 2024-10-08:
After some more testing and noticing weird behavior surrounding time_t values, it looks like Arduino is declaring time_t as 64-bit while PlatformIO is declaring it as 32-bit. This is coming from the different versions of the esp32 toolchain each build system is using, PlatformIO has _WANT_USE_LONG_TIME_T defined however Arduino does not.

My suspicion is that storing this 64-bit time_t in RTC memory corrupts it, as correctSystemClock always prints 0 for timeAsleep, and a garbage value for rtcCorrectionFactor. But I need to look into it more, if I can't develop a workaround I'll update the instructions to install the latest 2.x version of arduino-esp32.

wuspy, 2024-10-08:
Ok so the issue with the 64-bit time_t was purely logging related, I just needed to change the format specifiers. Everything seems to be working across Arduino IDE and PlatformIO now. #27 is updated, I'll probably merge it tomorrow after a bit more testing.

TumangShenyon, 2024-10-09:
Didn't had time to test again in Arduino IDE, but you were right, works well with PlatformIO (never used before, very cool)
I see another typo in a log (or maybe i'm wrong)
time_util.cpp line 154, it's recv and not Result you want to put in the log, right?
Apart from that, great job, i learned so much on esp32 with your code, THKS !

wuspy, 2024-10-09:
Yep you're completely right, I'll update that too.

Closed 2024-10-10.

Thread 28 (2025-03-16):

access point

jojkopeter, 2025-03-16:
Unfortunately, the access point won't start and the configuration cannot be performed. Please help.

jojkopeter, 2025-03-17:
Hello,
Can you please tell me how to get this calendar to work? After flashing, it only shows 00.
Do I need to install an app?
Thank you in advance for your reply.
Regards,
Peter

lividhen, 2025-03-18:
Nothing external is needed besides a device that can connect to a 2.4ghz WiFi network for configuration. What is it showing on screen? Is it just 00 where the days are? I would suggest plugging in the esp32 on the back in to a power source and then pressing the reset button, that should put it back in to setup mode.

wuspy, 2025-03-18:
There should be instructions on the screen saying to connect to USB power, then press the reset button. After doing this, the screen should change and show you a WiFi access point and a QR code to connect to it. Is it not doing this? If not, then I can think of a few possibilities

- You're not using the EzSBC board, as this board has a way to detect if it's running on USB power and most other boards don't. Specifically, when on USB power, IO19 is pulled high.
- You might have a wire getting pinched or some poor soldering somewhere that's connecting IO19 to ground.
- EzSBC updated their board in a way where USB power detection no longer works. I find this unlikely, but I haven't purchased a board from them in almost a year so anything's possible.

jojkopeter, 2025-03-18:
hallo, vielen dank für die rückmeldung. Was meinst du mit "Außer einem Gerät, das sich mit einem 2,4-GHz-WLAN-Netzwerk verbinden kann, wird für die Konfiguration nichts Externes benötigt"? Wie komme ich zum Setup? Musst man sich mit ESP32 über seine eigene WiFi ssid?

Here is my device

/

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

jojkopeter, 2025-03-18:
Hello again, I wanted to flash the code with Platformio, but unfortunately there are several problems compiling the code, making flashing impossible. Can you please help me?

wuspy, 2025-03-19:
That isn't the EzSBC board, so no, power detection isn't going to work on it for entering setup mode. You can test the setup on it though, by figuring out which physical pin corresponds to IO19 and connecting that to 3v3, then pressing reset. If you want to use this board long term, you can hook up a switch on that pin to trigger it, and of course you'll need to modify the case to fit it. You'll also need to run some power consumption tests to measure how much current this draws in sleep to see if it's even a good choice for use long term, you really need something in the microamp range if you want a year or more of battery life.

As for the platformIO issues, can you post the build errors?

jojkopeter, 2025-03-19:
Hello,
Thank you for your feedback.
Here are the errors on Platformio:

 *  Executing task: platformio run

Processing EzSBC (platform: espressif32; board: esp32dev; framework: arduino)
-------------------------------------------------------------------------------------------------------------------------------------------------------------------------------------------------------------------
Verbose mode can be enabled via `-v, --verbose` option
CONFIGURATION: https://docs.platformio.org/page/boards/espressif32/esp32dev.html
PLATFORM: Espressif 32 (2023.6.2) > Espressif ESP32 Dev Module
HARDWARE: ESP32 240MHz, 320KB RAM, 4MB Flash
DEBUG: Current (cmsis-dap) External (cmsis-dap, esp-bridge, esp-prog, iot-bus-jtag, jlink, minimodule, olimex-arm-usb-ocd, olimex-arm-usb-ocd-h, olimex-arm-usb-tiny-h, olimex-jtag-tiny, tumpa)
PACKAGES:
 - framework-arduinoespressif32 @ 2.0.9
 - tool-esptoolpy @ 1.40602.0 (4.6.2)
 - tool-mklittlefs @ 1.203.210628 (2.3)
 - tool-mkspiffs @ 2.230.0 (2.30)
 - toolchain-xtensa-esp32 @ 8.4.0+2021r2-patch5
Converting portal_calendar.ino
LDF: Library Dependency Finder -> https://bit.ly/configure-pio-ldf
LDF Modes: Finder ~ chain, Compatibility ~ soft
Found 35 compatible libraries
Scanning dependencies...
Dependency Graph
|-- ArduinoJson @ 7.3.1
|-- ESP Async WebServer @ 3.0.6
|-- WiFi @ 2.0.0
|-- HTTPClient @ 2.0.0
|-- Async TCP @ 3.1.4
|-- DNSServer @ 2.0.0
|-- Preferences @ 2.0.0
|-- SPI @ 2.0.0
|-- FS @ 2.0.0
|-- AsyncTCP_RP2040W @ 1.2.0
|-- WebServer @ 2.0.0
Building in release mode
Compiling .pio/build/EzSBC/src/Configuration.cpp.o
Compiling .pio/build/EzSBC/src/Display.cpp.o
Compiling .pio/build/EzSBC/src/DisplayGDEW075T7.cpp.o
Compiling .pio/build/EzSBC/src/localization.cpp.o
Compiling .pio/build/EzSBC/src/portal_calendar.ino.cpp.o
Compiling .pio/build/EzSBC/src/qrcodegen.cpp.o
Configuration.cpp: In lambda function:
Configuration.cpp:146:75: error: no matching function for call to 'AsyncJsonResponse::AsyncJsonResponse(bool, int)'
             AsyncJsonResponse *response = new AsyncJsonResponse(true, 8192);
                                                                           ^
In file included from Configuration.h:2,
                 from Configuration.cpp:2:
.pio/libdeps/EzSBC/ESP Async WebServer/src/AsyncJson.h:113:5: note: candidate: 'AsyncJsonResponse::AsyncJsonResponse(bool)'
     AsyncJsonResponse(bool isArray = false) : _isValid{false} {
     ^~~~~~~~~~~~~~~~~
.pio/libdeps/EzSBC/ESP Async WebServer/src/AsyncJson.h:113:5: note:   candidate expects 1 argument, 2 provided
In file included from Configuration.h:2,
                 from Configuration.cpp:2:
.pio/libdeps/EzSBC/ESP Async WebServer/src/AsyncJson.h:80:7: note: candidate: 'AsyncJsonResponse::AsyncJsonResponse(const AsyncJsonResponse&)'
 class AsyncJsonResponse : public AsyncAbstractResponse {
       ^~~~~~~~~~~~~~~~~
.pio/libdeps/EzSBC/ESP Async WebServer/src/AsyncJson.h:80:7: note:   candidate expects 1 argument, 2 provided
.pio/libdeps/EzSBC/ESP Async WebServer/src/AsyncJson.h:80:7: note: candidate: 'AsyncJsonResponse::AsyncJsonResponse(AsyncJsonResponse&&)'
.pio/libdeps/EzSBC/ESP Async WebServer/src/AsyncJson.h:80:7: note:   candidate expects 1 argument, 2 provided
Configuration.cpp:149:66: warning: 'ArduinoJson::V731PB22::JsonObject ArduinoJson::V731PB22::JsonArray::createNestedObject() const' is deprecated: use add<JsonObject>() instead [-Wdeprecated-declarations]
                 JsonObject network = networks.createNestedObject();
                                                                  ^
In file included from .pio/libdeps/EzSBC/ArduinoJson/src/ArduinoJson.hpp:56,
                 from .pio/libdeps/EzSBC/ArduinoJson/src/ArduinoJson.h:9,
                 from Configuration.h:1,
                 from Configuration.cpp:2:
.pio/libdeps/EzSBC/ArduinoJson/src/ArduinoJson/compatibility.hpp:140:19: note: declared here
 inline JsonObject JsonArray::createNestedObject() const {
                   ^~~~~~~~~
Configuration.cpp: In lambda function:
Configuration.cpp:162:71: error: no matching function for call to 'AsyncJsonResponse::AsyncJsonResponse(bool, int)'
         AsyncJsonResponse *response = new AsyncJsonResponse(false, 512);
                                                                       ^
In file included from Configuration.h:2,
                 from Configuration.cpp:2:
.pio/libdeps/EzSBC/ESP Async WebServer/src/AsyncJson.h:113:5: note: candidate: 'AsyncJsonResponse::AsyncJsonResponse(bool)'
     AsyncJsonResponse(bool isArray = false) : _isValid{false} {
     ^~~~~~~~~~~~~~~~~
.pio/libdeps/EzSBC/ESP Async WebServer/src/AsyncJson.h:113:5: note:   candidate expects 1 argument, 2 provided
In file included from Configuration.h:2,
                 from Configuration.cpp:2:
.pio/libdeps/EzSBC/ESP Async WebServer/src/AsyncJson.h:80:7: note: candidate: 'AsyncJsonResponse::AsyncJsonResponse(const AsyncJsonResponse&)'
 class AsyncJsonResponse : public AsyncAbstractResponse {
       ^~~~~~~~~~~~~~~~~
.pio/libdeps/EzSBC/ESP Async WebServer/src/AsyncJson.h:80:7: note:   candidate expects 1 argument, 2 provided
.pio/libdeps/EzSBC/ESP Async WebServer/src/AsyncJson.h:80:7: note: candidate: 'AsyncJsonResponse::AsyncJsonResponse(AsyncJsonResponse&&)'
.pio/libdeps/EzSBC/ESP Async WebServer/src/AsyncJson.h:80:7: note:   candidate expects 1 argument, 2 provided
Configuration.cpp: In lambda function:
Configuration.cpp:272:72: error: no matching function for call to 'AsyncJsonResponse::AsyncJsonResponse(bool, int)'
         AsyncJsonResponse *response = new AsyncJsonResponse(false, 1024);
                                                                        ^
In file included from Configuration.h:2,
                 from Configuration.cpp:2:
.pio/libdeps/EzSBC/ESP Async WebServer/src/AsyncJson.h:113:5: note: candidate: 'AsyncJsonResponse::AsyncJsonResponse(bool)'
     AsyncJsonResponse(bool isArray = false) : _isValid{false} {
     ^~~~~~~~~~~~~~~~~
.pio/libdeps/EzSBC/ESP Async WebServer/src/AsyncJson.h:113:5: note:   candidate expects 1 argument, 2 provided
In file included from Configuration.h:2,
                 from Configuration.cpp:2:
.pio/libdeps/EzSBC/ESP Async WebServer/src/AsyncJson.h:80:7: note: candidate: 'AsyncJsonResponse::AsyncJsonResponse(const AsyncJsonResponse&)'
 class AsyncJsonResponse : public AsyncAbstractResponse {
       ^~~~~~~~~~~~~~~~~
.pio/libdeps/EzSBC/ESP Async WebServer/src/AsyncJson.h:80:7: note:   candidate expects 1 argument, 2 provided
.pio/libdeps/EzSBC/ESP Async WebServer/src/AsyncJson.h:80:7: note: candidate: 'AsyncJsonResponse::AsyncJsonResponse(AsyncJsonResponse&&)'
.pio/libdeps/EzSBC/ESP Async WebServer/src/AsyncJson.h:80:7: note:   candidate expects 1 argument, 2 provided
Configuration.cpp: In lambda function:
Configuration.cpp:285:72: error: no matching function for call to 'AsyncJsonResponse::AsyncJsonResponse(bool, int)'
         AsyncJsonResponse *response = new AsyncJsonResponse(false, 4096);
                                                                        ^
In file included from Configuration.h:2,
                 from Configuration.cpp:2:
.pio/libdeps/EzSBC/ESP Async WebServer/src/AsyncJson.h:113:5: note: candidate: 'AsyncJsonResponse::AsyncJsonResponse(bool)'
     AsyncJsonResponse(bool isArray = false) : _isValid{false} {
     ^~~~~~~~~~~~~~~~~
.pio/libdeps/EzSBC/ESP Async WebServer/src/AsyncJson.h:113:5: note:   candidate expects 1 argument, 2 provided
In file included from Configuration.h:2,
                 from Configuration.cpp:2:
.pio/libdeps/EzSBC/ESP Async WebServer/src/AsyncJson.h:80:7: note: candidate: 'AsyncJsonResponse::AsyncJsonResponse(const AsyncJsonResponse&)'
 class AsyncJsonResponse : public AsyncAbstractResponse {
       ^~~~~~~~~~~~~~~~~
.pio/libdeps/EzSBC/ESP Async WebServer/src/AsyncJson.h:80:7: note:   candidate expects 1 argument, 2 provided
.pio/libdeps/EzSBC/ESP Async WebServer/src/AsyncJson.h:80:7: note: candidate: 'AsyncJsonResponse::AsyncJsonResponse(AsyncJsonResponse&&)'
.pio/libdeps/EzSBC/ESP Async WebServer/src/AsyncJson.h:80:7: note:   candidate expects 1 argument, 2 provided
Configuration.cpp: In lambda function:
Configuration.cpp:459:131: warning: 'AsyncWebServerResponse* AsyncWebServerRequest::beginResponse_P(int, const String&, const uint8_t*, size_t, AwsTemplateProcessor)' is deprecated: Replaced by beginResponse(...) [-Wdeprecated-declarations]
         AsyncWebServerResponse *response = request->beginResponse_P(200, "text/html", &INDEX_HTML_DATA[0], sizeof(INDEX_HTML_DATA));
                                                                                                                                   ^
In file included from .pio/libdeps/EzSBC/ESP Async WebServer/src/AsyncJson.h:38,
                 from Configuration.h:2,
                 from Configuration.cpp:2:
.pio/libdeps/EzSBC/ESP Async WebServer/src/ESPAsyncWebServer.h:324:29: note: declared here
     AsyncWebServerResponse* beginResponse_P(int code, const String& contentType, const uint8_t* content, size_t len, AwsTemplateProcessor callback = nullptr) {
                             ^~~~~~~~~~~~~~~
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

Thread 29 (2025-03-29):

The code doesn't work! I

jojkopeter, 2025-03-29:
Total disaster.
The code doesn't work! I had the EZSBC board sent over from the USA, but the code won't compile in Platformio. Please help urgently.

wuspy, 2025-03-30:
Your other issue only showed warnings, if it is failing to compile post the build output and I'll take a look. If it is urgent, you can try building with Arduino IDE instead.

Closed 2025-03-30.

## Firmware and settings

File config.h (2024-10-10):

#ifndef PORTALCALENDAR_CONFIG_H
#define PORTALCALENDAR_CONFIG_H

enum class WeatherDisplayType : uint8_t
{
    FORECAST_5_DAY = 0,
    FORECAST_12_HOUR = 1,
};

enum class WeatherUnits : uint8_t
{
    IMPERIAL = 0,
    METRIC = 1,
};

enum class WeatherSecondaryInfo : uint8_t
{
    POP = 0,
    HUMIDITY = 1,
};

/**
 * Default values for settings
 */
#define DEFAULT_LOCALE "en"

#define DEFAULT_SHOW_DAY true
#define DEFAULT_SHOW_MONTH true
#define DEFAULT_SHOW_YEAR false

#define DEFAULT_HOSTNAME "portalcalendar"

#define DEFAULT_PRIMARY_NTP_SERVER "pool.ntp.org"
#define DEFAULT_SECONDARY_NTP_SERVER "time.google.com"

#define DEFAULT_PRIMARY_TIMEZONED_SERVER "timezoned.rop.nl"
#define DEFAULT_SECONDARY_TIMEZONED_SERVER "timezoned.jacobjordan.tech"

#define DEFAULT_WEATHER_DISPLAY_TYPE WeatherDisplayType::FORECAST_5_DAY
#define DEFAULT_WEATHER_UNITS WeatherUnits::IMPERIAL
#define DEFAULT_WEATHER_SECONDARY_INFO WeatherSecondaryInfo::POP
#define DEFAULT_WEATHER_START_HOUR 9
#define DEFAULT_USE_24H_TIME false

#define DEFAULT_2_NTP_SYNCS_PER_DAY true
#define DEFAULT_MAX_RTC_CORRECTION_FACTOR 0.025

/**
 * How long we'll wait for an NTP sync before giving up.
 * This is PER SERVER, so if there's no internet connection and 3 servers, the total timeout will be 3x this amount.
 */
#define NTP_TIMEOUT_SECONDS 5

/**
 * How long we'll wait for a timezone information lookup before giving up.
 * This is PER SERVER, so if there's no internet connection and 3 servers, the total timeout will be 3x this amount.
 */
#define TZ_LOOKUP_TIMEOUT_SECONDS 5

/**
 * How long we'll wait for the Wi-Fi to connect before giving up.
 */
#define WIFI_CONNECTION_TIMEOUT_SECONDS 10

/**
 * Controls how long before midnight the processor is woken up for the first and second NTP syncs.
 * 
 * Two NTP syncs per day are performed per day because the internal clock in the ESP32 is very inaccurate.
 * 
 * The first time should be set to the maximum possible amount you expect the internal clock to be off in one day, since it will sleep for an entire day
 * and be woken at this time. The second one should be set to the maximum possible amount it will drift in the time betwen the first sync and midnight.
 * 
 * If the clock is running +MINUTES_BEFORE_MIDNIGHT_TO_SYNC_1 fast per day, then in reality it will be woken up MINUTES_BEFORE_MIDNIGHT_TO_SYNC_1 * 2
 * minutes before midnight, which is the maximum duration the NTP measurement will be deemed acceptable for. Any faster than that, and multiple
 * first stage NTP syncs will happen per day, which wastes battery.
 * 
 * If the clock is running -MINUTES_BEFORE_MIDNIGHT_TO_SYNC_1 slow per day, then it will wake up and sync exactly at midnight. Any slower than that,
 * and it won't wake wake up in time for midnight and the date changeover will be late.
 * 
 * The default values correspond to the maximum inaccuracy specified in the ESP32's datasheet, I recommend you don't touch them.
 */
#define MINUTES_BEFORE_MIDNIGHT_TO_SYNC_1 72
#define MINUTES_BEFORE_MIDNIGHT_TO_SYNC_2 8

/**
 * How many hours we'll go without internet before showing an error. This really shouldn't be longer than a couple days, since the internal
 * clock in the ESP32 is usually off by double-digit minutes per day.
 */
#define ERROR_AFTER_HOURS_WITHOUT_INTERNET 24

/**
 * SSID for the configuration access point
 */
#define AP_SSID "PortalCalendar"

/**
 * Password for the configuration access point. By default, a random 8-digit number is used for the password. Enabling this will make
 * it use the same password every time.
 */
// #define AP_PASS "12345678"

/**
 * Port assignments
 */
#define NTP_LOCAL_PORT_START 4242
#define TIMEZONED_LOCAL_PORT_START 2342

/**
 * Pin assignments
 */
#define SPI_BUS         HSPI
#define DIN_PIN         13 // COPI
#define CLK_PIN         14 // SCK
#define CS_PIN          15 // CS
#define DC_PIN          23 // Any OUTPUT pin
#define RESET_PIN       33 // Any OUTPUT pin
#define BUSY_PIN        27 // Any INPUT pin
#define PWR_PIN         32 // Any OUTPUT pin, unused prior to Rev2.3 driver board
#define PD_PIN          19 // Pin that changes when the device is on USB/DC power
#define PD_PIN_STATE    HIGH

/**
 * Enables the internal pullup on GPIO0 (Mode button) for boards that don't have a external pullup resistor on that pin.
 * The EzSBC does have one. If you're using a different board and it bootloops with weather enabled then this option is needed.
 * This may increase power usage in deep sleep.
 */
// #define ENABLE_GPIO0_PULLUP

/**
 * Disables display output. Useful for testing the code on an isolated board without requiring it to be connected to a display.
 */
// #define HEADLESS

/**
 * Normally the config server will start if the ESP32 is reset while plugged into USB.
 * This prevents that behavior so that the logs printed by DEBUG can be inspected.
 */
// #define DISABLE_MANUAL_CONFIG_SERVER_ACTIVATION

/**
 * Run the webserver connected to a local Wi-Fi network instead of creating an AP. This allows easily testing
 * the website, but connecting to Wi-Fi won't be available and will simply return mock responses based on the
 * Wi-Fi network it's already connected to.
 */
// #define DEV_WEBSERVER
// #define DEV_WEBSERVER_WIFI_SSID "ssid"
// #define DEV_WEBSERVER_WIFI_PASS "password"

#endif // PORTALCALENDAR_CONFIG_H

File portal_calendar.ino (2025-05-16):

#include <Arduino.h>
#include <WiFi.h>
#include <math.h>
#include "global.h"
#include "Configuration.h"
#include "time_util.h"
#include "Display.h"
#include "driver/rtc_io.h"
#include "weather.h"

const uint8_t ACTION_NTP_SYNC = 0b001;
const uint8_t ACTION_TZ_SYNC = 0b010;
const uint8_t ACTION_WEATHER_SYNC = 0b100;

/**
 * A bitmask of the actions above. Controls what is scheduled to be performed on scheduledWakeup.
 */
RTC_DATA_ATTR uint8_t scheduledActions = 0;
/**
 * The next scheduled wakeup time.
 */
RTC_DATA_ATTR time_t scheduledWakeup = 0;
/**
 * Time the current deep sleep cycle was started. Needed for RTC drift correction.
 */
RTC_DATA_ATTR time_t sleepStartTime = 0;

/**
 * Stores the current day of the year displayed
 */
RTC_DATA_ATTR int displayedYDay = 0;

RTC_DATA_ATTR bool showWeather = false;
RTC_DATA_ATTR time_t displayedWeatherTime = 0;

void deepSleep(time_t seconds)
{
    time(&sleepStartTime);
    scheduledWakeup = sleepStartTime + seconds;
    correctSleepDuration(&seconds);
    log_i("Sleeping for %llds, scheduled wakeup is %s\n\n", (long long)seconds, printTime(scheduledWakeup));

    if (Config.getWeatherEnabled()) {
        // Enable wakeup on boot button
        #ifdef ENABLE_GPIO0_PULLUP
        esp_sleep_pd_config(ESP_PD_DOMAIN_RTC_PERIPH, ESP_PD_OPTION_ON);
        rtc_gpio_pullup_en(GPIO_NUM_0);
        rtc_gpio_pulldown_dis(GPIO_NUM_0);
        #endif // ENABLE_GPIO0_PULLUP
        esp_sleep_enable_ext1_wakeup(0x1 << GPIO_NUM_0, ESP_EXT1_WAKEUP_ALL_LOW);
    }

    // Enable timer wakeup
    esp_sleep_enable_timer_wakeup((uint64_t)seconds * uS_PER_S);
    esp_deep_sleep_start();
}

void stopWifi()
{
    if (WiFi.getMode() != WIFI_OFF) {
        log_i("Stopping Wi-Fi");
        unsigned long start = millis();
        WiFi.disconnect(true, true);
        WiFi.mode(WIFI_OFF);
        log_i("Wi-Fi shutdown took %lums", millis() - start);
    }
}

void error(String message)
{
    log_i("Sleeping with error");
    stopWifi(); // Power down wifi before updating display to limit current draw from battery
    Display.error(message, true);
    deepSleep(SECONDS_PER_HOUR);
}

void errorNoWifi()
{
    error(
        "NO WI-FI CONNECTION\n\n"
        "Your Wi-Fi network is either down, out of range, "
        "or you entered the wrong password.\n\n"
        "Wi-Fi Name:\n"
        + Config.getWifiSsid()
    );
}

void errorNtpFailed()
{
    error(
        "NO INTERNET CONNECTION\n\n"
        "Your Wi-Fi network works, but the NTP servers didn't "
        "respond. This probably means your Wi-Fi has no internet "
        "connection. Or, you configured the NTP servers yourself, "
        "in which case you might have messed something up.\n\n"
        "NTP servers:\n"
        + Config.getPrimaryNtpServer() + "\n"
        + Config.getSecondaryNtpServer()
    );
}

void errorTzLookupFailed()
{
    error(
        "TIMEZONE LOOKUP FAILED\n\n"
        "Your timezone is either invalid, or the timezone servers "
        "are down. If you configured the timezone servers "
        "yourself, you might have messed something up.\n\n"
        "Your timezone:\n"
        + Config.getTimezoneName() + "\n\n"
        "Timezone servers:\n"
        + Config.getPrimaryTimezonedServer() + "\n"
        + Config.getSecondaryTimezonedServer()
    );
}

void errorInvalidOwmApiKey()
{
    error(
        "INVALID OPENWEATHERMAP API KEY\n\n"
        "OpenWeatherMap.org says your API key is invalid. "
        "You probably have an issue with your configuration. "
        "Go to your account -> My API Keys and make sure "
        "the one there matches the one you entered. Or, just "
        "disable the weather feature entirely."
    );
}

void errorCrash()
{
    log_w("Crash detected on last boot");
    error(
        "UNKNOWN ERROR\n\n"
        "The calendar experienced a fatal error. "
        "If this problem persists, open an issue describing "
        "what you were doing, along with any other details "
        "that may be relevant, at:\n\n"
        "https://github.com/wuspy/portal_calendar/issues\n\n"
        "To troubleshoot this error yourself, follow the "
        "instructions in the project README to enable debug "
        "logs, and use a serial monitor to attempt to locate "
        "where the error is occurring."
    );
}

void errorBrownout()
{
    // Brownout was likely caused by the wifi radio, so hopefully there's still
    // enough power to refresh the display
    log_w("Brownout detected");
    Display.error(
        "REPLACE BATTERIES\n\n"
        "If the device does not restart automatically "
        "after new batteries have been inserted, "
        "press the RESET button on the back.",
        false
    );
    // Sleep forever
    esp_sleep_disable_wakeup_source(ESP_SLEEP_WAKEUP_ALL);
    esp_deep_sleep_start();
}

void onSettingsSaved()
{
    // Reset state
    scheduledWakeup = 0;
    scheduledActions = 0;
    savedTimezone[0] = '\0';
    showWeather = Config.getWeatherEnabled();
    displayedYDay = 0;
    displayedWeatherTime = 0;
    lastWeatherSync = 0;
}

void showWelcomeScreen()
{
    log_i("Showing welcome screen");
    Display.showWelcomeScreen();
    // Sleep forever
    esp_sleep_disable_wakeup_source(ESP_SLEEP_WAKEUP_ALL);
    esp_deep_sleep_start();
}

void runScheduledActions()
{
    // Sync timezone

    if ((scheduledActions & ACTION_TZ_SYNC) || !isSystemTimeValid()) {
        if (Config.connectToSavedWifi()) {
            String tz;
            TimezonedResult result = getPosixTz(
                { Config.getPrimaryTimezonedServer(), Config.getSecondaryTimezonedServer() },
                Config.getTimezoneName(),
                tz
            );
            if (result == TimezonedResult::Ok) {
                setTimezone(tz.c_str());
                scheduledActions &= ~ACTION_TZ_SYNC;
            } else if (!savedTimezone[0]) {
                errorTzLookupFailed();
            }
        } else if (!savedTimezone[0]) {
            // WiFi didn't connect and we have no idea what timezone we're in
            errorNoWifi();
        }
    }

    // Sync time

    if ((scheduledActions & ACTION_NTP_SYNC) || !lastNtpSync) {
        if (Config.connectToSavedWifi()) {
            if (syncNtp({ Config.getPrimaryNtpServer(), Config.getSecondaryNtpServer() })) {
                scheduledActions &= ~ACTION_NTP_SYNC;
            } else if (!isSystemTimeValid()) {
                // Sync unsuccesful and we have no idea what time it is
                errorNtpFailed();
            }
        } else if (!isSystemTimeValid()) {
            // WiFi didn't connect and we have no idea what time it is
            errorNoWifi();
        }
    }

    // Sync weather
    
    if ((scheduledActions & ACTION_WEATHER_SYNC) || !lastWeatherSync) {
        if (Config.getWeatherEnabled()) {
            if (Config.connectToSavedWifi()) {
                OwmResult result = refreshWeather();
                switch (result) {
                    case OwmResult::SUCCESS:
                        scheduledActions &= ~ACTION_WEATHER_SYNC;
                        break;
                    case OwmResult::INVALID_API_KEY:
                        errorInvalidOwmApiKey();
                    default:
                        // Ignore other OWM errors because weather isn't critical
                        break;
                }
            } else if (!lastWeatherSync) {
                errorNoWifi();
            }
        } else {
            // Weather not enabled, do nothing and clear the action
            scheduledActions &= ~ACTION_WEATHER_SYNC;
        }
    }
}

void setup()
{
    time_t t;
    time(&t);

    #if CORE_DEBUG_LEVEL > 0
    Serial.begin(115200);
    #endif

    setTimezone();
    if (sleepStartTime) {
        correctSystemClock(t - sleepStartTime);
        time(&t);
        sleepStartTime = 0;
    }

    log_i("Waking up at %s", printTime(t));

    const esp_reset_reason_t resetReason = esp_reset_reason();
    const esp_sleep_wakeup_cause_t wakeupCause = esp_sleep_get_wakeup_cause();

    log_i("Wakeup cause: %u, Reset reason: %u", wakeupCause, resetReason);

    switch (resetReason) {
        case ESP_RST_BROWNOUT:
            errorBrownout();
            break;
        case ESP_RST_PANIC:
        case ESP_RST_INT_WDT:
        case ESP_RST_TASK_WDT:
        case ESP_RST_WDT:
            errorCrash();
            break;
    }

    Config.begin();

    // Check if configuration is required
    if (!Config.isConfigured()) {
        log_i("Not configured");
        if (Config.isOnUsbPower()) {
            log_i("On USB power");
            Config.runConfigServer(onSettingsSaved);
        } else {
            log_i("Not on USB power");
            showWelcomeScreen();
        }
    }
    // Check for wakeup from boot button press
    else if (wakeupCause == ESP_SLEEP_WAKEUP_EXT1 && Config.getWeatherEnabled() && isSystemTimeValid()) {
        log_i("Toggling showWeather");
        showWeather = !showWeather;
    }
    // Check if config server is manually started by pressing reset while plugged in
    else if (wakeupCause == ESP_SLEEP_WAKEUP_UNDEFINED && Config.isOnUsbPower()) {    
        #ifndef DISABLE_MANUAL_CONFIG_SERVER_ACTIVATION
        log_i("Config server was manually started");
        Config.runConfigServer(onSettingsSaved);
        #else
        log_i("Config server would have been manually started, but is disabled");
        #endif
    }

    time(&t);

    if (t >= scheduledWakeup) {
        runScheduledActions();
        scheduledWakeup = 0;
    }

    stopWifi();
    WiFi.setHostname(Config.getHostname().c_str());

    time(&t);
    tm now;
    localtime_r(&t, &now);

    // Check if display should be updated

    bool needsDisplayUpdate = now.tm_yday != displayedYDay;

    if (Config.getWeatherEnabled()) {
        needsDisplayUpdate = needsDisplayUpdate
            || static_cast<bool>(displayedWeatherTime) != showWeather
            || (showWeather
                && lastWeatherSync != displayedWeatherTime
                && getSecondsToMidnight(&now) > SECONDS_BEFORE_MIDNIGHT_TO_SYNC_1 * 2);
    }

    if (needsDisplayUpdate) {
        log_i("Updating display at %s", printTime(t));
        Display.update(&now, getLocale(Config.getLocale()), showWeather);
        displayedYDay = now.tm_yday;
        displayedWeatherTime = Config.getWeatherEnabled() && showWeather ? lastWeatherSync : 0;
    }

    time(&t);

    if (scheduledWakeup) {
        log_i("Wakeup is already scheduled");
        // max with 0 is needed in case the display was updated since the first scheduledWakeup check,
        // which could make it in the past now despite being in the future before the display update
        deepSleep(max((time_t)0, scheduledWakeup - t));
    }

    // Schedule next wakeup

    localtime_r(&t, &now);
    int secondsToMidnight = getSecondsToMidnight(&now) + 1; // +1 to make sure it's actually at or past midnight
    log_i("%d seconds to midnight", secondsToMidnight);
    // failedActions doesn't care about timezone sync because as long as we've got it once it's probably still correct
    uint8_t failedActions = scheduledActions & ~ACTION_TZ_SYNC;
    if (failedActions) {
        log_w("Sync failed, scheduling retry");
        if (secondsToMidnight <= SECONDS_BEFORE_MIDNIGHT_TO_SYNC_1) {
            if (Config.getTwoNtpSyncsPerDay()) {
                if (secondsToMidnight <= SECONDS_BEFORE_MIDNIGHT_TO_SYNC_2) {
                    // Try to sync 3 more times before midnight
                    deepSleep(min(secondsToMidnight, SECONDS_BEFORE_MIDNIGHT_TO_SYNC_2 / 3));
                }
                // Try to sync 3 more times before the 2nd scheduled sync
                deepSleep(min(
                    secondsToMidnight - SECONDS_BEFORE_MIDNIGHT_TO_SYNC_2,
                    (SECONDS_BEFORE_MIDNIGHT_TO_SYNC_1 - SECONDS_BEFORE_MIDNIGHT_TO_SYNC_2) / 3
                ));
            }
            // Try to sync 4 more times before midnight
            deepSleep(min(secondsToMidnight, SECONDS_BEFORE_MIDNIGHT_TO_SYNC_1 / 4));
        }
        // Keep trying to sync every hour
        deepSleep(min(secondsToMidnight - SECONDS_BEFORE_MIDNIGHT_TO_SYNC_1, 3600));
    }

    if (secondsToMidnight <= SECONDS_BEFORE_MIDNIGHT_TO_SYNC_1 * 2) {
        if (!Config.getTwoNtpSyncsPerDay() || secondsToMidnight <= SECONDS_BEFORE_MIDNIGHT_TO_SYNC_2 * 2) {
            // Sleep until midnight
            log_i("Sleeping until midnight");
            deepSleep(secondsToMidnight);
        }
        // Sleep until second NTP sync
        scheduledActions = ACTION_NTP_SYNC;
        log_i("Sleeping for 2nd sync");
        deepSleep(secondsToMidnight - SECONDS_BEFORE_MIDNIGHT_TO_SYNC_2);
    }

    // Sleep until first NTP sync
    scheduledActions = ACTION_NTP_SYNC | ACTION_TZ_SYNC | ACTION_WEATHER_SYNC;
    log_i("Sleeping for 1st sync");
    deepSleep(secondsToMidnight - SECONDS_BEFORE_MIDNIGHT_TO_SYNC_1);
}

void loop()
{
}

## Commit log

2022-07-31 Simplify sleep & NTP sync lifecycle, and prevent unnecessary wakeups if the clock is running fast.
    [portal_calendar.ino]
2022-07-31 Fix missing return in getPosixTz
    [portal_calendar.ino]
2022-08-02 Fix some formatting and typos
    [config.h, display_GDEW075T7.cpp, portal_calendar.ino]
2022-08-11 Initial commit for frame
    [back.stl, cover.stl, front.stl]
2022-08-11 Frame: add more chamfers, fix USB connector alignment
    [back.stl, cover.stl]
2022-08-12 Frame: Fix swapped dimensions on backplate screw standoff pockets. Give ribbon cable a bit more clearance on cover. Reword 'reboot' to 'boot' and use a larger font. Move front revision number to a no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
    [back.stl, cover.stl, front.stl]
2022-08-13 Frame: Add a 5th screw to the cover. Make the hat clamping standoffs slightly bigger. Draft more surfaces to prevent pinching wires.
    [back.stl, cover.stl, front.stl]
2022-08-13 Change display rotation to 270 to match frame. Add a timeout to waitUntilIdle and remove unnecesary FLG command.
2022-08-16 Update pin assignments. Move more options to config.h. Show an error after enough time without internet.
    [config.h, portal_calendar.ino]
2022-08-18 Use the NTP routine from ezTime instead of the awful one that comes in the ESP32 libraries. Perform 2 NTP syncs per day to make the changeover more accurate now that NTP syncs are actually fast. Meas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
    [config.h, portal_calendar.ino]
2022-10-04 Add ability to show weather in place of chamber icons. Refactor to make code a bit cleaner.
2022-10-08 Better error messages. Improve config documentation. Clean up code. Support WiFi networks with no password. Support multiline text rendering in display.
    [DisplayGDEW075T7.cpp, config.h, portal_calendar.ino]
2022-10-19 Add icons from Portal 2. Show chamber icon sets from the actual game instead of just randomizing them.
2022-10-22 Remove geoip timezone feature because it's unreliable and doesn't really make sense for this application anyway. Initial commit for readme.
    [config.h, portal_calendar.ino]
2022-12-23 Add low battery detection. Fix handling of multiple timezoned servers.
    [config.h, portal_calendar.ino]
2023-01-21 Update weather location debug print statement
2023-02-25 Update includes for time_util, fix narrowing warning
    [portal_calendar.ino]
2023-02-26 Fix filename case and default language
    [config.h]
2023-02-27 Allow SPI pins to be specified
2023-03-01 Refactor strings file. Update i18n docs. Replace MAERZ with MÄRZ
    [config.h]
2023-03-04 Allow toggling between chamber and weather
2023-04-05 Frame revision 4: fix labeling of boot & reset buttons, Label boot button as 'mode'.
    [back.stl, cover.stl, front.stl]
2023-04-06 Rewrite scheduling and RTC correction code to not break on arbitrary powerups. Remove ENABLE_RTC_CORRECTION option. Mark noreturn functions. Label boot/reset buttons correctly.
    [config.h, portal_calendar.ino]
2023-04-06 Fix ribbon cable draft on cover
    [cover.stl]
2023-04-19 Keep RTC periph powered on for the internal pullup on IO0, and make that pullup configurable since it could increase power usage.
2023-04-21 Initial commit for wifi configuration
    [Configuration.h]
2023-04-22 Move config types, power detect pin to config.h
    [Configuration.h]
2023-05-29 Replace custom logger with esp32 builtin
    [config.h, portal_calendar.ino]
2023-11-14 Support mDNS on the connected wifi network. Add hostname validation. Add ability to forget the saved wifi network.
    [Configuration.h]
2023-12-07 Fix crash if unplugged before configured
    [portal_calendar.ino]
2023-12-09 Fix possible framebuffer overflow
    [DisplayGDEW075T7.cpp]
2023-12-09 Fix Arduino IDE build
    [Configuration.h]
2023-12-09 platformio: update ArduinoJson
2023-12-10 Wifi connection refactoring
    [Configuration.h]
2023-12-13 Add STEP file
    [frame.step]
2024-02-13 Add support for waveshare Rev2.3 driver board
2024-10-07 Update for arduino-esp32 v3 and latest Arduino IDE
2024-10-09 Minor refactoring and typo fix
    [portal_calendar.ino]
2025-05-11 Update ArduinoJson and ESPAsyncWebServer, add an error screen to aid in debugging and prevent crash loops
    [Configuration.h]
2025-05-26 Add frame around start screen QR code
